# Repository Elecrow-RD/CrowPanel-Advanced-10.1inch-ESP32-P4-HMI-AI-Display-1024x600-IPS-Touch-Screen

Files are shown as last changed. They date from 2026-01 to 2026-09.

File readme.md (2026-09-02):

### 1, Product picture



### 2, Product version number

| | Hardware | Software | Remark |
| ---- | --- | --- | --- |
| 1 | V1.0 | V1.0 | old |
| 1 | V1.1 | V1.1 | old |
| 1 | V1.2 | V1.2 | latest |

**Version 1.1 Update**

The C6 module version 1.1 adds support for 4-wire SDIO communication. Additionally, the arrangement of the SDIO pins has been adjusted, with the pin mappings of the data lines D0–D3 changing from **IO14, IO15, IO16, IO17** to **IO17, IO16, IO15, IO14**. 

**Version 1.2 Update** 

Based on the V1.1 version, V1.2 further optimized the communication stability of the LoRa wireless module. At the same time, the signal pins of the wireless module socket were re-allocated: the original **IO53 and IO54** were adjusted to **IO27 and IO28** respectively, and correspondingly, **IO27 and IO28** were adjusted to **IO53 and IO54** respectively.

### 3, product information

| **Main Chip-ESP32-P4NRW32** | |
| --- | --- |
| CPU/SoC | **ESP32-P4**RISC-V 32-bit dual-core processor for HP systems, running at up to 400 MHz; RISC-V 32-bit single-core processor for LP systems, running at up to 40 MHz |
| System Memory | 768 KB L2MEM（HP）32 KB SRAM（LP）8 KB TCM 32 MB PSRAM |
| Memory | 128 KB ROM（HP）16 KB ROM（LP）16 MB Flash |
| Development Environment | ESP-IDF、Arduino IDE |
| **Screen** | |
| Size | 10.1 inch |
| Resolution | 1024*600 |
| Display Panel | IPS Panel |
| Touch Panel | Capacitive Touch, Single/5-point Touch |
| Viewing Angle | 178° |
| Brightness | 400 cd/m²(Typ.) |
| Color Depth | 16.7M (8-bit) |
| **Wireless Communication - Onboard Antenna** | |
| WiFi | Support 2.4GHz(Wi-Fi6), 802.11a/b/g/n |
| Bluetooth | Support Bluetooth 5.3 and BLE |
| Other | Zigbee、LoRa、nRF2401、Matter、Thread and Wi-Fi Halow (Optional) |
| **Interface/Function** | |
| Interface | USB2.0, UART, I2C, GPIO female headers, SD card holder, battery socket, speaker jack, camera header, module female headers, etc. |
| Function | Audio amplifier, battery charge management, USB to UART, dual microphones, etc. |
| **Button/LED Indicator** | |
| Reset Button | Yes, press to reset device |
| Boot Button | Yes, press and hold the power button to burn the program |
| Power Button | Switch On/Off |
| PWR | Device power on/off indication |
| CHG | Lithium battery charging status, Low battery state |
| **Other** | |
| Installation method | All around mounting holes(M3 3.2mm), embedded, shell assembly |
| Operating temperature | -20~70 °C |
| Storage temperature | -30~80 °C |
| Power Input | 5V/2A, USB or UART terminal |
| Dimensions | 248*147mm |

### Functional description of the product's internal interfaces:

| Pin Name | Description | Connector Type |
| :--- | :--- | :--- |
| SPK | Output audio signals to connect to speakers. The main board comes with a power amplifier chip circuit. | PH2.0-2P |
| PWR | Power LED. | |
| RST | Reset button. Press it to reset the system. | |
| boot | | |
| UART1 | Builds communication between Logic modules, including the serial communication module and the print module. | HY2.0-4P |
| I2C | Builds communication between Logic modules, including the serial communication module and the print module. | HY2.0-4P |
| UART3-IN | Input power supply and serial communication functionality | XH2.54-4P |
| BAT | Connect the lithium battery. (with battery charging circuit) | PH2.0-2P |

### 4, Use the driver module

| Name | dependency library |
| ---- | --- |
| LVGL | lvgl/lvgl@9.1(V1.2)<br />lvgl/lvgl@8.3(V1.0/V1.1) |

### 5,Quick Start
##### ESP-IDF starts

**Note**: This is an IDF course. Before proceeding, ensure you have **Visual Studio Code** and the **IDF **environment installed. The IDF version must be **5.4.2** or higher.

1.Right-click on an empty space in the project folder and select "Open with VS Code" to open the project.


2.In the IDF plug-in, select the port, then compile and flash



### 6,Folder structure.
|--3D file： Contains 3D model files (.stp) for the hardware. These files can be used for visualization, enclosure design, or integration into CAD software.

|--Datasheet: Includes datasheets for components used in the project, providing detailed specifications, electrical characteristics, and pin configurations.

|--Eagle_SCH&PCB: Contains **Eagle CAD** schematic (`.sch`) and PCB layout (`.brd`) files. These are used for circuit design and PCB manufacturing.

|--example: Provides example code and projects to demonstrate how to use the hardware and libraries. These examples help users get started quickly.

|--factory_firmware: Stores pre-compiled factory firmware that can be directly flashed onto the device. This ensures the device runs the default functionality.

|--factory_sourcecode:  Contains the source code for the factory firmware, allowing users to modify and rebuild the firmware as needed.

|--libraries: Includes necessary libraries required for compiling and running the project. These libraries provide drivers and additional functionalities for the hardware.

### 7,Pin definition

#### ESP32-P4 10.1 inch and IPS Display Wiring Pins:
**DSI = Display Serial Interface**is a high-speed, low-power display interface standard defined by the MIPI Alliance, most commonly used in smartphones, tablets, Raspberry Pi devices, and embedded Linux systems.



DSI Pin connection

DSI_DATAN0--IO40

DSI_DATAN0--IO39

DSI_DATAN0--IO36

DSI_DATAN0--IO35

DSI_CLKN--IO37

DSI_CLKP--IO38

DSI_REXT--IO34

#### ESP32-P4 and Touch Driver Wiring：
i2c address: 0x5D/0x14.(The INT pin level during reset of the GT911 touch chip determines the device address.)

INT Low Level(0x5D);

INT High Level(0x14).



Pin connection

I2C1_SCL(IO46)

I2C1_SDA(IO45)

INT_TP(IO42)

RESET_TP(IO40)

#### ESP32-P4 and wireless module wiring pins：

Output voltage: 3.3V Output current: 1A max. Use: The power supply communicates with the wireless module.



Pin connection

#define RADIO_GPIO_CLK 8

#define RADIO_GPIO_MISO 7

#define RADIO_GPIO_MOSI 6

#ifdef CONFIG_BSP_SX1262_ENABLED

#define SX1262_GPIO_BUSY 9

#define SX1262_GPIO_IRQ 53

#define SX1262_GPIO_NRST 54

#define SX1262_GPIO_NSS 10

#ifdef CONFIG_BSP_NRF2401_ENABLED

#define NRF24_GPIO_IRQ 9

#define NRF24_GPIO_CE 53

#define NRF24_GPIO_CS 54

ESP32-P4 and Audio out：



Pin connection

#define AUDIO_GPIO_LRCLK    21   // GPIO pin number for LRCLK (Left-Right Clock)

#define AUDIO_GPIO_BCLK     22   // GPIO pin number for BCLK (Bit Clock)

#define AUDIO_GPIO_SDATA    23   // GPIO pin number for SDATA (Serial Data)

#define AUDIO_GPIO_CTRL     30   // GPIO pin number for audio amplifier control

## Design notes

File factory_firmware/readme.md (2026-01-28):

# How to install the factory demo firmware with flash download tool?

#### 1.Preparation:

- USB C cable
- Laptop/PC
- CrowPanel Advanced 7inch ESP32-P4 HMI AI Display
- Flash download tool

Check whether the materials on the PCBA board are defective. Such as less material, false welding, tin and other bad phenomena.

#### 2.Flash the firmware 

##### Step1 Connect the ESP32 P4 display to the laptop/PC with USB-C cable. The power indicator will light up.

##### Step2 Open the flash download tool. 

flash02

For the  Crowpanel Advance HMI ESP32 P4  AI Display, the chip select ESP32-P4:

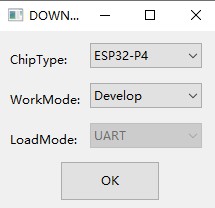
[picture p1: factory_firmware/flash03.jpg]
flash03


##### Step3

①Choose the firmware files;

②Enter the address: 

bootloader.bin------0x2000

partitions-table.bin--------0x8000

esp_brookesia_demo.bin------0x10000

storage.bin-------0xb10000

③Check the firmware files;

④Select the correct port number;

⑤Click “Start” to download

flash1

##### Step4 Press the reset button to show the demo.

#####

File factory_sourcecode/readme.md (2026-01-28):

Factory display code to show the boot screen and the official lvgl display case.
When users re-download the factory cases, they need to first put the libraries in the link in libraries as required.

Factory codes are compiled by IDF.

### Program download link: https://drive.google.com/drive/folders/1gTY6aRsqKJku3hoj4YmE7d5dIDBvLP6W?usp=sharing

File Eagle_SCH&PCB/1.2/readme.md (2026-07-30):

# ESP32-P4 Display 10.1 inch V1.2 Product Hardware Driver Guide

| Item | Details |
|---|---|
| Document Version | V1.0 |
| Applicable Hardware | ESP32-P4 Display 10.1 inch V1.2 |
| Document Date | 2026-07-30 |
| Author | OpenAI Codex (compiled from the project schematics and validation code) |
| Schematic Baseline | `1.2/ESP32-P4 Display 10.1 inch V1.2.sch` and the PDF of the same name |
| Driver Baseline | `idf-code/Lesson01` through `Lesson17` |
| Software Platform | ESP-IDF, primarily targeting ESP32-P4; FreeRTOS |

## 1. Document Purpose and Evaluation Criteria

This document is intended for hardware maintenance, ESP-IDF driver porting, and onboarding handoffs. Cross-validation follows this order of precedence:

1. Constants and initialization code that are actually compiled in the validated BSP;
2. Default Kconfig values and component dependencies in the code;
3. Eagle `.sch` components and netlist;
4. Visual/textual annotations in the PDF schematic;
5. Comments and README files, used only as supplementary information.

When the code and schematic differ, this document records the code values as the “currently effective configuration” while retaining the schematic values in the discrepancy table. The code repository does not include a complete mass-production firmware project, the actual `sdkconfig`, test logs, or module firmware. Therefore, “validated” means that the repository provides a standalone Lesson example for the feature; it does not mean that all peripherals can operate simultaneously.

Status definitions:

- **Code-validated**: The repository contains complete initialization and usage examples.
- **Hardware-confirmed**: The hardware is present in the schematic, but the repository provides no direct driver, or it is managed internally by the chip/module firmware.
- **Optional external device**: Connected through an expansion connector; not an onboard component.
- **NC**: Explicitly marked as not populated in the schematic; must not be treated as a standard installed component.

## 2. System Architecture and Peripheral Overview

| Category | Component/Function | Schematic Designator | Interface | Current Status | Primary Code |
|---|---|---:|---|---|---|
| Main Controller | ESP32-P4NRW32 | U7 | Internal peripheral matrix | Code-validated | All Lessons |
| Boot Storage | W25Q128JVSIQ 128 Mbit NOR Flash | IC11 | Dedicated QSPI | Hardware-confirmed; managed by ROM/IDF | No standalone BSP |
| Wireless Coprocessor | ESP32-C6-MINI-1-N4 | IC1 | 6-line SDIO + EN | Code-validated | Lesson16, 17 |
| Display | 10.1-inch 1024×600, EK79007 timing controller | J21 | 2-lane MIPI-DSI/DPI | Code-validated | Lesson07, 09, 13-16 |
| Touch | GT911 (on the touch FPC/display module) | FPC2 | I2C + RST + INT | Code-validated | Lesson05, 06, 09, 16 |
| Backlight | MT9201 boost constant-current driver | U6 | GPIO31 PWM/EN, GPIO29 power gating | Partially code-validated | `bsp_illuminate` |
| Camera | SC2336 module | FPC1 | 2-lane MIPI-CSI + SCCB | Code-validated | Lesson13 |
| Memory Card | microSD | J5 | SDMMC 1-bit | Code-validated | Lesson08, 12 |
| Audio Output | I2S digital audio + ES8311/NS4168/NS4263B path | IC6/U3/U4 | I2S + I2C + GPIO | Partially code-validated | Lesson11, 12 |
| Audio Input | Onboard PDM microphone; additional ES7210 multichannel ADC | -/IC5 | PDM; I2S+I2C | PDM code-validated; ES7210 hardware-confirmed only | Lesson11 |
| USB Device | USB 2.0 OTG Type-C | J16 | ESP32-P4 USB D+/D- | Code-validated | Lesson06 |
| USB-to-Serial | CH340K + Type-C | U1/J1 | USB-UART0 | Hardware-confirmed; OS driver | Programming/logging port |
| UART Expansion | UART1, UART3/5 V input | J2/J10 | 3.3 V UART, level-shifted 5 V UART | UART1/2 code-validated | Lesson04, 14, 15 |
| I2C Expansion | HY2.0 4P, 7P Header | J13/J11 | 3.3 V I2C | Code-validated | Lesson05, 09, 10 |
| Environmental Sensor | DHT20 (external) | J13 | I2C | Code-validated | Lesson10 |
| LoRa | SX1262 (external) | J9/J11 | SPI + BUSY/IRQ/RST/NSS | Code-validated; Kconfig pin discrepancies | Lesson14 |
| 2.4 GHz | nRF24L01 (external) | J9/J11 | SPI + IRQ/CE/CS | Code-validated; Kconfig pin discrepancies | Lesson15 |
| GPIO Expansion | 2×12 Header | J7 | GPIO2-5, 25, 49-54, 3.3/5 V | Hardware-confirmed | User application |
| Buttons | P4 RESET, BOOT | K4/K3 | CHIP_PU, boot configuration | Hardware-confirmed | ROM boot logic |
| Battery Charging | TP4059 + battery connector | U2/J3 | Analog power, CHG/STD | Hardware-confirmed | Monitored by STC8 auxiliary controller |
| Power Auxiliary Controller | STC8H1K08-36I | U5 | ADC/GPIO/SPI/UART | Hardware-confirmed; no source code | None |
| Power Tree | RY3420, MT3406, MT3608, ME6211 series | U9/U10/U16/IC2/3/4/7/8 | DC-DC/LDO | Hardware-confirmed | ESP32-P4 internal LDOs are invoked |

## 3. Currently Effective ESP32-P4 Pin Assignment Table

| GPIO/Dedicated Pin | Current Function | Electrical/Multiplexing Notes | Code Basis |
|---:|---|---|---|
| 6/7/8 | External wireless SPI MOSI/MISO/SCLK | SPI3_HOST, 8 MHz; J9 through series resistors/filtering | Lesson14/15 `bsp_wireless.h` |
| 9/10 | SX1262 BUSY/NSS or nRF24 IRQ | Mutually exclusive between modules | Lesson14/15 |
| 12/13 | Camera SCCB SDA/SCL | I2C1, internal pull-ups, 100 kHz | Lesson13 |
| 14/15/16/17/18/19 | ESP32-C6 SDIO D3/D2/D1/D0/CLK/CMD | Dedicated onboard 6-line bus | Lesson16/17 + schematic |
| 20 | Microphone L/R selection | Schematic net `MIC_L/R`; not configured by the current PDM BSP | Schematic |
| 21/22/23 | I2S LRCLK/BCLK/DOUT | 16 kHz, 16 bit, stereo | Lesson11/12 |
| 24/26 | PDM CLK/DIN | 16 kHz mono, left channel | Lesson11 |
| 25 | GPIO expansion | J7-17 | Schematic |
| 27/28 | UART2 TX/RX; J9/J11 wireless control pins, used by the BSP as IRQ/RST or CE/CS | **The schematic intentionally multiplexes these signals; software must ensure mutual exclusion** | Schematic + Lesson14/15 |
| 29 | LCD backlight power MOS gate | Present in the schematic; not controlled by the current display BSP | Schematic |
| 30 | Audio amplifier control | Push-pull output; active-low in code | Lesson11/12 |
| 31 | LCD backlight PWM/EN | LEDC 30 kHz, 11 bit | Lesson07+ |
| 32 | ESP32-C6 EN | Main controller can reset/power down the C6; examples do not operate it directly | Schematic |
| 33/34 | UART3 RX/TX (5 V input expansion) | Level-shifted to J10 | Defined in Lesson04 but this pin group is not selected |
| 37/38 | UART0 TX/RX | CH340K programming/logging | Schematic |
| 39/43/44 | microSD D0/CLK/CMD | SDMMC slot 0, 1-bit, 10 MHz | Lesson08/12 |
| 40/42 | GT911 RST/INT | Configured active-low; current driver primarily uses polling | Lesson05/09 |
| 41 | LCD RESET | Connected in the schematic; EK79007 BSP uses `reset_gpio_num=-1` | Discrepancy; see Section 15 |
| 45/46 | System I2C SDA/SCL | I2C0, open-drain, internal pull-ups, 400 kHz | Lesson05/09/10/16 |
| 47/48 | UART1 TX/RX | J2 3.3 V; GPIO48 is also used by the LED example | Lesson02/04 + schematic |
| 49-54 | GPIO expansion | J7; 53/54 are the wireless Kconfig-recommended control pins | Schematic/Kconfig |
| USB DP/DM | USB2 D+/D- | Dedicated PHY to J16 | Lesson06 |
| Dedicated DSI/CSI Pins | MIPI D-PHY | Two data lanes plus one clock lane each | Lesson07/13 |

## 4. Main Controller, Clocks, and Boot Storage

### 4.1 ESP32-P4NRW32 (U7)

- All main-controller examples are based on ESP-IDF/FreeRTOS; the code uses the IDF driver layer rather than directly accessing chip registers.
- The external main crystal Y2 is 40 MHz; Y4 is 32.768 kHz.
- K4 pulls `CHIP_PU/P4_RST_EN` low to reset the device; K3 controls `SPI_BOOT`. The schematic labels high as SPI Boot and low as Download Boot.
- High-bandwidth display/camera buffers depend on SPIRAM. LVGL uses double buffering in SPIRAM, while the camera uses cache-aligned SPIRAM USERPTR buffers.
- The display/wireless examples acquire the ESP32-P4 internal LDO3 at 2500 mV and LDO4 at 3300 mV before initializing peripherals. This sequence must not be omitted during porting.

```c
esp_ldo_channel_config_t ldo3 = { .chan_id = 3, .voltage_mv = 2500 };
esp_ldo_channel_config_t ldo4 = { .chan_id = 4, .voltage_mv = 3300 };
ESP_ERROR_CHECK(esp_ldo_acquire_channel(&ldo3, &ldo3_handle));
ESP_ERROR_CHECK(esp_ldo_acquire_channel(&ldo4, &ldo4_handle));
```

### 4.2 W25Q128JVSIQ (IC11)

- Dedicated Flash bus: `FLASH_CS/CK/WP/HOLD/D/Q`; it does not use peripheral pins listed in the general-purpose GPIO table.
- The component model indicates a capacity of 128 Mbit (16 MiB). Actual usable partitions are determined by the project’s `partitions.csv` and flashing configuration.
- It is managed by the ROM bootloader and the ESP-IDF SPI flash layer. The application must not initialize this bus again.

## 5. Display, Touch, and Backlight

### 5.1 EK79007 MIPI-DSI Display

Currently effective parameters: 2 data lanes, 900 Mbps lane rate, 8-bit DBI commands and parameters; 1024×600, RGB565, 51 MHz DPI pixel clock; horizontal timing 160/70/160 and vertical timing 23/10/12 (back porch/pulse/front porch).

```c
esp_lcd_dsi_bus_config_t bus = {
    .bus_id = 0, .num_data_lanes = 2, .lane_bit_rate_mbps = 900,
};
esp_lcd_dpi_panel_config_t dpi = {
    .dpi_clock_freq_mhz = 51,
    .pixel_format = LCD_COLOR_PIXEL_FORMAT_RGB565,
    .video_timing = { .h_size=1024, .v_size=600,
        .hsync_back_porch=160, .hsync_pulse_width=70, .hsync_front_porch=160,
        .vsync_back_porch=23, .vsync_pulse_width=10, .vsync_front_porch=12 },
};
```

Dependencies: `esp_lcd_mipi_dsi`, `espressif/esp_lcd_ek79007 ^1.0.2`, `esp_lvgl_port ^2.6.0`, and LVGL 8.3.11. The LVGL task priority is `configMAX_PRIORITIES-4`, with a 16 KiB stack, a 5 ms timer, and a maximum sleep duration of 10 ms; full-frame double buffers reside in SPIRAM.

### 5.2 GT911 Touch

- I2C0: SDA=GPIO45, SCL=GPIO46; 7-bit address, 400 kHz; internal pull-ups enabled and a 7-cycle glitch filter.
- RST=GPIO40 and INT=GPIO42, both configured with active level 0; coordinates are 1024×600, with no XY swap or mirroring.
- The driver first attempts `ESP_LCD_TOUCH_IO_I2C_GT911_ADDRESS`, then tries `..._BACKUP` if the first attempt fails (common GT911 addresses are 0x5D/0x14; the final values are determined by the component header).
- The application polling path calls `esp_lcd_touch_read_data()`. Although INT is passed to the component, the examples do not register a user GPIO ISR.

Initialization sequence: acquire LDOs → `i2c_init()` → `touch_init()` → DSI/LVGL → register the LVGL touch input → turn on the backlight.

### 5.3 Backlight

- GPIO31 connects to MT9201 EN/backlight control, using LEDC low-speed timer0/channel0, the PLL divider clock, 30 kHz, and 11-bit resolution.
- `brightness=0` outputs duty 0; for nonzero values, duty=`brightness*18+200`. The caller must limit the value to 0-100, or the duty may exceed the 11-bit maximum of 2047.
- The schematic also includes GPIO29→Q11→`LCD_BK_VDD` power gating. The current BSP does not drive GPIO29 high; whether it is controlled by the power-on default or other firmware must be confirmed on physical hardware.
- The J21 panel also requires analog supplies such as 9.6 V AVDD, 18 V VGH, -6 V VGL, and 3.3 V VCOM. These are generated by U16/discrete circuitry and are not GPIO-driven.

## 6. SC2336 Camera

- FPC1 connector: 2-lane MIPI-CSI (D0/D1/CLK differential pairs), SCCB, XVCLK, RESET, and DOVDD 1.8 V/AVDD 2.8 V power supplies.
- SCCB uses I2C port 1, SDA=GPIO12 and SCL=GPIO13, with internal pull-ups at 100 kHz.
- The driver configures `reset_pin=-1` and `pwdn_pin=-1`, reuses the existing SCCB bus handle, and uses `ESP_VIDEO_MIPI_CSI_DEVICE_NAME` as the video node.
- RGB565 is enforced through V4L2 `VIDIOC_G_FMT/S_FMT`; the resolution is negotiated by the sensor driver and is not hard-coded in the BSP.
- At least two capture buffers are used with `V4L2_MEMORY_USERPTR`, SPIRAM, and cache alignment; H/V flip can be controlled through Kconfig.
- ISP parameter file `sc2336_custom.json`: 50 Hz anti-flicker, including AWB/AGC, noise reduction, gamma, sharpening, and a color matrix.
- Dependencies: ESP-IDF >=5.4.0, `esp_cam_sensor ^1.2.0`, `esp_sccb_intf ^0.0.5`, and `esp_video ^1.1.0`.

Note: The schematic includes a `CSI_RESET` control net, but the code explicitly uses -1. Retain the code configuration during migration unless the GPIO reset path is revalidated.

## 7. microSD

- GPIO43=CLK, GPIO44=CMD, and GPIO39=D0; SDMMC_HOST slot 0, 1-bit, 10 MHz, with internal pull-ups.
- J5 D1, D2, and CS are not used in the current 1-bit mode; the corresponding pads/pull-ups are also visible in the schematic.
- The FATFS mount point is `/sdcard`; automatic formatting is disabled, up to five files may be open, and the allocation unit is 16 KiB.

```c
sdmmc_host_t host = SDMMC_HOST_DEFAULT();
host.slot = SDMMC_HOST_SLOT_0;
host.max_freq_khz = 10000;
sdmmc_slot_config_t slot = SDMMC_SLOT_CONFIG_DEFAULT();
slot.clk = GPIO_NUM_43; slot.cmd = GPIO_NUM_44; slot.d0 = GPIO_NUM_39;
slot.width = 1; slot.flags |= SDMMC_SLOT_FLAG_INTERNAL_PULLUP;
```

The current BSP does not use card-detect CD for hot-plug detection. FATFS should be unmounted before inserting or removing the card to avoid file-system corruption.

## 8. Audio Input and Output

### 8.1 Currently Validated Playback Path

- GPIO21=LRCLK/WS, GPIO22=BCLK, and GPIO23=DOUT; I2S standard TX, 16 kHz, 16 bit, stereo, with an MCLK multiple of 256, but `mclk=I2S_GPIO_UNUSED`.
- GPIO30 controls the audio amplifier and is configured as a push-pull output with no pull-up or pull-down. In the code, `set_Audio_ctrl(true)` actually outputs a low level, so the control is active-low.
- The Lesson12 SD audio playback example uses the same GPIOs; the input file format/sample rate must match the actual I2S configuration.

### 8.2 Currently Validated Recording Path

- PDM RX: GPIO24=CLK and GPIO26=DIN; 16 kHz, 16 bit, mono, left slot.
- 8× downsampling, BCLK divider 8, 35.5 Hz high-pass, and amplify=1.
- The recording buffer is allocated at 32000 bytes/s. The example limits recordings to 60 seconds and, after recording, converts and plays them back through the playback path.

### 8.3 Audio Components Present in the Schematic but Not Fully Driven by the Examples

- ES7210 (IC5): multichannel audio ADC with I2C control and I2S/TDM output; the repository does not contain register initialization.
- ES8311 (IC6): codec with I2C control lines on the 3.3 V side, connected to I2S MCLK/SCLK/LRCK/SDOUT; the current playback BSP does not initialize its I2C registers.
- NS4168 (U3/U13) is marked NC in the schematic and must not be treated as a standard installed amplifier.
- NS4263B (U4) is the onboard analog amplifier path; the enable/disable and mute polarity should still be confirmed using waveforms from physical hardware.

## 9. USB and Serial Ports

### 9.1 USB2 Device Port J16

- Dedicated USB DP/DM connects directly to the ESP32-P4; both Type-C CC pins have 5.1 kΩ pull-down resistors, configuring the port as a device.
- Lesson06 uses a TinyUSB HID mouse: one HID interface, IN endpoint 0x81, 16-byte packets, and a 10 ms interval; it declares 100 mA and remote wakeup.
- Dependency: `espressif/esp_tinyusb ^1.1`. Touch is polled every 10 ms and converted into relative mouse movement.

### 9.2 USB-UART Programming Port J1/U1

- The CH340K connects to USB1 D+/D-, with UART0 connected to ESP32-P4 GPIO37 (TX)/GPIO38 (RX); DTR/RTS participate in automatic programming/reset.
- The application does not initialize the CH340K; the host PC uses the WCH CH340 driver. This port is used for both programming and logging, so the application should not remap UART0.

### 9.3 UART Expansion

- J2: 3.3 V UART1, GPIO47 TX and GPIO48 RX.
- J10: external 5 V UART input interface, connected through level shifting to GPIO34 TX and GPIO33 RX.
- Lesson04 actually initializes `UART_NUM_2` and maps it to GPIO47/48: 115200, 8N1, no flow control, and a 2048-byte RX buffer.
- Lesson14/15 optionally use `UART_NUM_1` at 115200 8N1 for transparent UART communication. GPIO27/28 in the header match the J9/J11 schematic connections, but the Kconfig defaults specify GPIO53/54 instead.

## 10. Onboard ESP32-C6 Wi-Fi

- The ESP32-P4 itself has no Wi-Fi; IC1 ESP32-C6-MINI-1-N4 serves as the wireless coprocessor.
- SDIO: P4 GPIO14/15/16/17/18/19 → C6 IO23/22/21/20/19/18 (D3/D2/D1/D0/CLK/CMD). GPIO32 controls C6 EN.
- The C6 has its own UART0 and BOOT test/programming network; do not confuse it with the P4 application UART.
- P4 software depends on `espressif/esp_hosted ~2.7.0` and `espressif/esp_wifi_remote ^0.16.1`; the application still calls the standard `esp_wifi_*` API.
- Lesson17 covers STA, SoftAP, and AP+STA; the channel, maximum number of connections, and authentication threshold are controlled by Kconfig. The Lesson16 weather application uses STA.

Porting must ensure all of the following: the C6 is flashed with slave firmware compatible with the esp-hosted version; the P4 SDIO pin/width configuration matches the board-level connections; and the GPIO32 EN timing is correct. The repository does not include the C6 slave firmware or the complete system `sdkconfig`; these are external dependencies for reproducing Wi-Fi operation.

## 11. I2C Environmental Sensor and Expansion Ports

System I2C0 (GPIO45/46) connects to J13/J11 and the onboard codec control interface through BSS138 level shifting/pull-ups. The code uniformly configures bus devices for 7-bit addressing at 400 kHz.The DHT20 is an external device at address 0x38:

- After initialization, check the calibration status bits: `status & 0x18 == 0x18`;
- Send the measurement command `AC 33 00`, wait at least 80 ms, and then poll the busy bit;
- Read 7 bytes. CRC-8 uses an initial value of 0xFF and polynomial 0x31;
- Humidity and temperature are both 20-bit values and must be converted to `%RH` and `°C`.

The touchscreen, DHT20, ES8311, and external devices share bandwidth on the same I2C0 bus. Address conflicts and the total pull-up resistance must be checked before connecting a new module.

## 12. External Wireless Modules

### 12.1 Shared SPI Bus

SPI3_HOST, GPIO8 SCLK, GPIO7 MISO, GPIO6 MOSI, mode 0, 8 MHz, DMA auto; CS is controlled in software by RadioLib through a GPIO, with `spics_io_num=-1`. J9 provides SPI and 3.3/5 V, while the control pins come from additional expansion GPIOs.

### 12.2 SX1262 (Lesson14)

Current valid header-file values: BUSY=GPIO9, IRQ/DIO1=GPIO27, NRST=GPIO28, and NSS=GPIO10; these values match the J9/J11 connections. LoRa parameters: 915 MHz, BW 125 kHz, SF7, CR 7, private sync word, 22 dBm, preamble 8, and TCXO voltage parameter 1.6. TX/RX completion uses GPIO ISR callbacks. RX uses continuous receive with boosted gain.

### 12.3 nRF24L01 (Lesson15)

Current valid header-file values: IRQ=GPIO9, CE=GPIO27, and CS=GPIO28; these values match the J9/J11 connections. Parameters: 2400 MHz, 250 kbps, address width 5, pipe address `01 02 11 12 FF`, and SPI at 8 MHz.

The SX1262 and nRF24 share the SPI bus and control pins, so only one may be selected at compile time. Product compliance must confirm whether 915 MHz complies with regulations in the deployment region.

## 13. Power, Charging, and Auxiliary Control

| Power Domain/Device | Function | Software Relationship |
|---|---|---|
| TP4059 U2 | Single-cell lithium battery charging from 5 V input, CHG/STD status | Monitored by STC8; no direct P4 control |
| STC8H1K08 U5 | Charging LEDs, VBAT ADC, power control | No STC8 firmware in the repository; maintenance gap |
| U9 RY3420 | 5 V→3.3 V DC-DC | Always on/hardware-enabled |
| U10 MT3406 | 5 V→approximately 1.2 V DC-DC | P4 DCDC power domain |
| U16 MT3608 | Front-end power supply for LCD high voltage | Hardware-controlled |
| IC2 ME6211 1.8 V | Camera DOVDD | Hardware-enabled |
| IC3 ME6211 2.8 V | Camera AVDD | Hardware-enabled |
| IC4 ME6211 1.8 V NC | Alternative LCD VDD | NC, not required |
| IC7/IC8 ME6211 3.3 V | Audio/auxiliary control power | Hardware-enabled |
| MT9201 U6 | Constant-current boost converter for LCD LEDs | GPIO31 EN/PWM |
| GPIO29/Q11 | Backlight input power gating | Currently omitted from the BSP; must be verified on actual hardware |

Type-C J1, J16, and the external 5 V input provide multiple power entry points, and the schematic includes diode/MOSFET isolation. During maintenance, never bypass the isolation and connect different power supplies in parallel. All expansion GPIOs use 3.3 V logic. Only J10, which is explicitly marked as having level conversion, can accept 5 V UART signals.

## 14. Expansion Connectors

| Connector | Key Signals | Voltage/Purpose |
|---|---|---|
| J7 2×12 | GPIO49, 2, 3, 4, 5, 50, 51, 52, 25, 53, 54 | Includes 3.3 V, 5 V, and GND; GPIOs are not 5 V tolerant |
| J9 7P | SPI SCLK/MISO/MOSI, GPIO27, 3.3 V, 5 V, GND | External SX1262/nRF24 |
| J11 7P | I2C SDA/SCL, GPIO28/9/10 | Wireless/I2C expansion |
| J13 HY2.0 | 3.3 V, SDA, SCL, GND | DHT20 and other I2C sensors |
| J2 HY2.0 | RXD1, TXD1, 3.3 V, GND | 3.3 V UART |
| J10 XH2.54 | UART_IN TX/RX, 5 V, GND | External UART with level conversion |
| J8 1×4 | STC8 power/programming-related signals | For auxiliary-control maintenance only |

## 15. Schematic and Code Differences/Conflicts

| ID | Item | Schematic/Kconfig | Current Working Code | Assessment and Handling |
|---|---|---|---|---|
| D01 | Wireless control pin configuration | Both schematic J9/J11 and the header file use GPIO27/28; Kconfig defaults to GPIO53/54 | GPIO27/28 hardcoded in the header file | Record 27/28 based on the effective code and schematic; the Kconfig values are currently ineffective. If changed to 53/54, the external wiring must also be changed and revalidated |
| D02 | Wireless configuration source | Kconfig defines `CONFIG_*GPIO*` | The header file does not reference Kconfig and instead defines macros directly | Changes in menuconfig do not take effect; migration requires standardizing on `CONFIG_...` |
| D03 | GPIO48 LED | The schematic shows GPIO48 as `RXD1` routed to J2; no independent onboard LED net was found | Lesson02 directly configures GPIO48 as push-pull output and describes high level as “LED on” | Record as operational according to the example, but it drives the UART RX net; do not use it simultaneously with UART1. Verify the silkscreen/board revision on actual hardware |
| D04 | LCD reset | J21 `LCD_RESET` connects to P4 GPIO41 | EK79007 uses `reset_gpio_num=-1` | Do not use GPIO reset according to the code; verify GPIO41 timing only if cold-start issues occur |
| D05 | Backlight power | GPIO29 controls Q11 `LCD_BK_VDD` | The BSP controls only GPIO31 PWM | May depend on a default pull-up or other firmware; GPIO29 must be tested and incorporated into production initialization |
| D06 | Camera reset | FPC1 has a `CSI_RESET` hardware net | `reset_pin=-1`, `pwdn_pin=-1` | Follow the code; do not independently drive shared pins such as GPIO46 based solely on the schematic |
| D07 | SD data width | J5 routes D0/D1/D2/CS | D0 only, 1-bit SDMMC | Not a conflict; follow the code for a more reliable 10 MHz 1-bit mode |
| D08 | Audio codec | The schematic includes ES7210/ES8311 | The examples use I2S/PDM directly without writing codec registers | Only demonstrates a simplified audio path; full codec functionality requires new driver validation |
| D09 | UART naming | Schematic signal names are UART1/UART3/UART2 | Lesson04 maps `UART_NUM_2` to GPIO47/48 | IDF UART controllers can be routed through the GPIO matrix; use GPIOs rather than variable names when determining connections during maintenance |
| D10 | GT911 address | The schematic does not specify the chip address | The component automatically tries the primary and alternate addresses | Follow the code; record the final address in the logs for maintenance |
| D11 | NS4168 | U3/U13 are marked NC | Audio descriptions may refer generically to an amplifier | Follow the BOM/actual hardware; do not create hard dependencies on NC devices |

The causes of these differences can be conclusively determined only after obtaining the hardware ECN, BOM, and test records. Current possibilities include unsynchronized board revisions, remnants from example migrations, or schematic labeling errors; this document does not treat possible causes as established facts.

## 16. Risks and Precautions

1. **GPIO27/28 resource conflict (High)**: The schematic multiplexes UART2 with the J9/J11 wireless control pins; they cannot be enabled simultaneously. If J7 GPIO53/54 are used instead, both the external wiring and BSP must be updated.
2. **GPIO48 conflict (High)**: The LED example shares a pin with UART1 RX; output mode may cause electrical contention with an external transmitter.
3. **5 V tolerance (High)**: ESP32-P4 GPIOs use 3.3 V logic. The presence of 5 V on J7/J9 does not mean the signal pins are 5 V tolerant.
4. **Backlight power sequencing (High)**: Complete DSI initialization and render the first frame before enabling GPIO29 power and GPIO31 PWM; use the reverse order during shutdown.
5. **Wi-Fi firmware coupling (High)**: The P4 `esp_hosted/esp_wifi_remote` version must match the C6 slave firmware.
6. **Power entry points (High)**: When USB, battery, and external 5 V supplies coexist, confirm that the isolation components are installed; never short the supplies together directly.
7. **MIPI signal integrity (High)**: DSI/CSI are controlled-impedance differential signals. Do not use jumper wires, long leads on ordinary probes, or arbitrary FPC substitutions.
8. **Memory pressure (Medium)**: A single 1024×600 RGB565 frame is approximately 1.17 MiB. Display double buffering plus camera double buffering requires sufficient SPIRAM.
9. **I2C pull-ups (Medium)**: Multiple onboard and external pull-ups connected in parallel may be too strong. At 400 kHz, verify the waveform and low-level sink current.
10. **SD hot-plugging (Medium)**: Card-detect handling is not currently implemented. Removing the card during writes may corrupt FATFS.
11. **Audio popping (Medium)**: GPIO30 is active low. Keep the amplifier disabled until the data is stable, and disable it only after the stream has stopped.
12. **LoRa regulations (Medium)**: 915 MHz and 22 dBm are not permitted in all regions. Production parameters must be adjusted for the target market.
13. **Security configuration (Medium)**: The Lessons contain example Wi-Fi SSIDs/passwords; they must not be included in production firmware.
14. **Missing auxiliary-control source code (Medium)**: The STC8 firmware is not in the repository, so the charging/power state machine cannot be fully audited or migrated.

## 17. Recommended System Initialization/Shutdown Sequence

Power-on initialization:

1. Confirm that the external 5 V/battery supply is stable, and keep the backlight and amplifier disabled;
2. Configure ESP32-P4 LDO3=2.5 V and LDO4=3.3 V;
3. Initialize the shared I2C0 bus, followed by the GT911 and other I2C devices;
4. Initialize MIPI-DSI, EK79007, and LVGL, and submit the first frame;
5. Confirm the GPIO29 backlight power-gating state, and then gradually increase GPIO31 from a low duty cycle;
6. Initialize the SD card, audio, and camera as needed; initialize camera SCCB before CSI/V4L2;
7. Start the ESP32-C6 and wait for hosted transport, then start `esp_wifi`;
8. Finally, enable the external wireless IRQ or UART after completing GPIO conflict checks.

Reverse the sequence for shutdown: stop application tasks/IRQs → stop Wi-Fi/wireless → stop the camera/release frame buffers → unmount the SD card → stop I2S and disable the amplifier → set backlight duty=0/disable power → release the display and LDOs.

## 18. Driver Migration Checklist

- [ ] Lock the hardware version to V1.2, along with the BOM and ECN; confirm all NC/DNP components.
- [ ] Ensure the target ESP-IDF meets the requirements of all components; standardizing on >=5.4.2 is recommended.
- [ ] Before copying the pin table, define the mutual-exclusion strategy for D01 and resolve D03 and D05.
- [ ] Enable PSRAM and verify DMA/cache alignment capabilities.
- [ ] First run individual tests for solid-color display output, touchscreen coordinates, SD read/write, audio loopback, and camera frame capture.
- [ ] Use a logic analyzer to verify I2C at 400/100 kHz, SPI at 8 MHz, SD at 10 MHz, and UART at 115200.
- [ ] Use an oscilloscope to verify GPIO30/31/29 polarity and power-on waveforms.
- [ ] Flash the matching version of the ESP32-C6 hosted firmware and test reconnection after disconnection.
- [ ] Then perform full-system concurrent stress testing: display + touchscreen + SD + audio + camera + Wi-Fi.
- [ ] Record the final `sdkconfig`, component lock file, C6 firmware hash, and test report.

## 19. Key Software Dependencies and Evidence Index

| Function | Software Layer/Component | Primary Evidence Files |
|---|---|---|
| GPIO/LEDC | ESP-IDF `driver/gpio.h`, `driver/ledc.h` | `Lesson02/.../bsp_extra.c`, `Lesson07/.../bsp_illuminate.c` |
| DSI/LVGL | ESP-IDF LCD + EK79007 + LVGL port | `Lesson07-Turn_on_the_screen/peripheral/bsp_illuminate/` |
| GT911/I2C | New IDF I2C master + esp_lcd_touch_gt911 | `Lesson05-Touchscreen/peripheral/` |
| SD | SDMMC + VFS FAT | `Lesson08-SD_Card_File_Reading/peripheral/bsp_sd/` |
| I2S/PDM | IDF I2S standard/PDM drivers | `Lesson11-Playback_After_Recording/peripheral/` |
| USB | TinyUSB/esp_tinyusb | `Lesson06-USB2.0/peripheral/bsp_usb/` |
| Camera | esp_video/V4L2 + esp_cam_sensor | `Lesson13-Camera_Real-Time/peripheral/bsp_camera/` |
| Wi-Fi | esp_hosted + esp_wifi_remote | `Lesson16.../idf_component.yml`, `Lesson17-Wi-Fi_function/` |
| SX1262/nRF24 | RadioLib 7.x + custom EspHal | `Lesson14.../bsp_wireless/`, `Lesson15.../bsp_wireless/` |
| Schematic Nets | Eagle 9.6.2 XML + PDF | `1.2/ESP32-P4 Display 10.1 inch V1.2.sch/.pdf` |

## 20. Maintenance Conclusions

The board’s verified primary path is ESP32-P4 + MIPI-DSI 1024×600 + GT911 + SDMMC + PDM/I2S + MIPI-CSI + ESP32-C6 hosted Wi-Fi. The schematic and code are generally consistent for the display, touchscreen, SD, camera data interface, primary audio GPIOs, and wireless J9/J11 connections. The main maintenance risks are GPIO27/28 function multiplexing and the Kconfig mismatch, GPIO48 LED/UART multiplexing, omission of backlight GPIO29 from the BSP, and missing source code for full codec/power auxiliary control. Before conducting concurrent multi-peripheral validation, any complete system integration must first resolve these discrepancies.

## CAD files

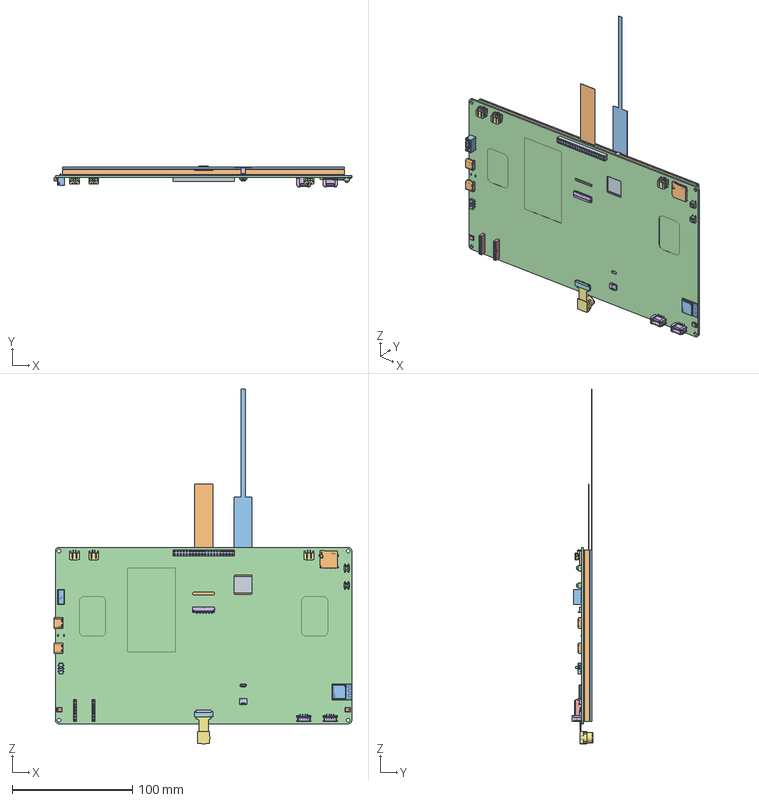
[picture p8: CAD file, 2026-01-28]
3D file/ESP32-P4-10_1-inch-20251230.stp
248.0 x 17.5 x 295.7 mm
LCD-10-1CUN
TP-10-1CUN
PCBA-10-1
FPC1_FPC-SMD_P0_50-24P_QCHF-SM
H1_HDR-SMD_40P-P2_54-V-F-R2-C20
USB-C-SMD_TYPE-C-6PIN-2MD x 2
CN2_CONN-TH_4P-P2_50_4PIN_CONN
LED x 2
HDR-SMD_7P-P2_54_HX-PM2_54-1X7P x 2
U4_CONN-SMD_4P-P2_00 x 2
CONN-SMD_2P-P2_00_BX-PH2_0-2PWT x 3
SW-SMD_MST22D18G2_SW-SMD_MST22D
FPC-SMD_P0_50-6P_QCHF-SM-H2_0_1
TF-SMD
WIFIM-SMD_61P-L16_6-W13_2-P0_80
SW-SMD_4P-L4_5-W4_5-P3_00 x 2
MIC-SMD_6P-L4_7-W3_8-P1_65-TL_M x 2
CONN-SMD_AFC24-S30FIC-00_CONN-S
AS-AG638A32M1-25

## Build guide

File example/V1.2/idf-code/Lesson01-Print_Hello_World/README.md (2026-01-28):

| Supported Targets | ESP32 | ESP32-C2 | ESP32-C3 | ESP32-C5 | ESP32-C6 | ESP32-C61 | ESP32-H2 | ESP32-P4 | ESP32-S2 | ESP32-S3 | Linux |
| --- | ----- | --- | --- | --- | --- | --- | --- | --- | --- | --- | ----- |

# Hello World Example

Starts a FreeRTOS task to print "Hello World".

(See the README.md file in the upper level 'examples' directory for more information about examples.)

## How to use example

Follow detailed instructions provided specifically for this example.

Select the instructions depending on Espressif chip installed on your development board:

- [ESP32 Getting Started Guide](https://docs.espressif.com/projects/esp-idf/en/stable/get-started/index.html)
- [ESP32-S2 Getting Started Guide](https://docs.espressif.com/projects/esp-idf/en/latest/esp32s2/get-started/index.html)

## Example folder contents

The project **hello_world** contains one source file in C language [hello_world_main.c](main/hello_world_main.c). The file is located in folder [main](main).

ESP-IDF projects are built using CMake. The project build configuration is contained in `CMakeLists.txt` files that provide set of directives and instructions describing the project's source files and targets (executable, library, or both).

Below is short explanation of remaining files in the project folder.

```
├── CMakeLists.txt
├── pytest_hello_world.py      Python script used for automated testing
├── main
│   ├── CMakeLists.txt
│   └── hello_world_main.c
└── README.md                  This is the file you are currently reading
```

For more information on structure and contents of ESP-IDF projects, please refer to Section [Build System](https://docs.espressif.com/projects/esp-idf/en/latest/esp32/api-guides/build-system.html) of the ESP-IDF Programming Guide.

## Troubleshooting

* Program upload failure

    * Hardware connection is not correct: run `idf.py -p PORT monitor`, and reboot your board to see if there are any output logs.
    * The baud rate for downloading is too high: lower your baud rate in the `menuconfig` menu, and try again.

## Technical support and feedback

Please use the following feedback channels:

* For technical queries, go to the [esp32.com](https://esp32.com/) forum
* For a feature request or bug report, create a [GitHub issue](https://github.com/espressif/esp-idf/issues)

We will get back to you as soon as possible.

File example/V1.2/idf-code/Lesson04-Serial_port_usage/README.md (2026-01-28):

| Supported Targets | ESP32 | ESP32-C2 | ESP32-C3 | ESP32-C6 | ESP32-H2 | ESP32-P4 | ESP32-S2 | ESP32-S3 |
| --- | ----- | --- | --- | --- | --- | --- | --- | --- |

# Example: GPIO

(See the README.md file in the upper level 'examples' directory for more information about examples.)

This test code shows how to configure GPIO and how to use it with interruption.

## GPIO functions:

| GPIO | Direction | Configuration |
| --- | --- | --- |
| CONFIG_GPIO_OUTPUT_0 | output | |
| CONFIG_GPIO_OUTPUT_1 | output | |
| CONFIG_GPIO_INPUT_0 | input | pulled up, interrupt from rising edge and falling edge |
| CONFIG_GPIO_INPUT_1 | input | pulled up, interrupt from rising edge |

## Test:
 1. Connect CONFIG_GPIO_OUTPUT_0 with CONFIG_GPIO_INPUT_0
 2. Connect CONFIG_GPIO_OUTPUT_1 with CONFIG_GPIO_INPUT_1
 3. Generate pulses on CONFIG_GPIO_OUTPUT_0/1, that triggers interrupt on CONFIG_GPIO_INPUT_0/1

 **Note:** The following pin assignments are used by default, you can change them by `idf.py menuconfig` > `Example Configuration`.

| | CONFIG_GPIO_OUTPUT_0 | CONFIG_GPIO_OUTPUT_1 | CONFIG_GPIO_INPUT_0 | CONFIG_GPIO_INPUT_1 |
| --- | --- | --- | --- | --- |
| ESP32C2/ESP32H2 | 8 | 9 | 4 | 5 |
| All other chips | 18 | 19 | 4 | 5 |

## How to use example

Before project configuration and build, be sure to set the correct chip target using `idf.py set-target <chip_name>`.

### Hardware Required

* A development board with any Espressif SoC (e.g., ESP32-DevKitC, ESP-WROVER-KIT, etc.)
* A USB cable for Power supply and programming
* Some jumper wires to connect GPIOs.

### Configure the project

### Build and Flash

Build the project and flash it to the board, then run the monitor tool to view the serial output:

Run `idf.py -p PORT flash monitor` to build, flash and monitor the project.

(To exit the serial monitor, type ``Ctrl-]``.)

See the [Getting Started Guide](https://docs.espressif.com/projects/esp-idf/en/latest/get-started/index.html) for full steps to configure and use ESP-IDF to build projects.

## Example Output

As you run the example, you will see the following log:

```
I (317) gpio: GPIO[18]| InputEn: 0| OutputEn: 1| OpenDrain: 0| Pullup: 0| Pulldown: 0| Intr:0
I (327) gpio: GPIO[19]| InputEn: 0| OutputEn: 1| OpenDrain: 0| Pullup: 0| Pulldown: 0| Intr:0
I (337) gpio: GPIO[4]| InputEn: 1| OutputEn: 0| OpenDrain: 0| Pullup: 1| Pulldown: 0| Intr:1
I (347) gpio: GPIO[5]| InputEn: 1| OutputEn: 0| OpenDrain: 0| Pullup: 1| Pulldown: 0| Intr:1
Minimum free heap size: 289892 bytes
cnt: 0
cnt: 1
GPIO[4] intr, val: 1
GPIO[5] intr, val: 1
cnt: 2
GPIO[4] intr, val: 0
cnt: 3
GPIO[4] intr, val: 1
GPIO[5] intr, val: 1
cnt: 4
GPIO[4] intr, val: 0
cnt: 5
GPIO[4] intr, val: 1
GPIO[5] intr, val: 1
cnt: 6
GPIO[4] intr, val: 0
cnt: 7
GPIO[4] intr, val: 1
GPIO[5] intr, val: 1
cnt: 8
GPIO[4] intr, val: 0
cnt: 9
GPIO[4] intr, val: 1
GPIO[5] intr, val: 1
cnt: 10
...
```

## Troubleshooting

For any technical queries, please open an [issue](https://github.com/espressif/esp-idf/issues) on GitHub. We will get back to you soon.

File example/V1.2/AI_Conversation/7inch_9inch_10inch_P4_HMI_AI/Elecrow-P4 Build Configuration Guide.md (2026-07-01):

# Elecrow P4 Development Board Build Configuration Guide

## 📋 How to Ensure the elecrow-p4-board Configuration Is Used During Build

### Method 1: Select the Board via menuconfig (Recommended)

This is the standard approach—choose the development board through the graphical configuration menu:

```bash
# 1. Set the build target to ESP32-P4
idf.py set-target esp32p4

# 2. Open the configuration menu
idf.py menuconfig

# 3. Navigate in the menu:
#    Xiaozhi Assistant → Board Type → Elecrow P4 Board
#    Press Space to select, then save and exit

# 4. Build
idf.py build

```

**Menu path**
```
Xiaozhi Assistant
  └─ Board Type
      └─ [*] Elecrow P4 Board  ← Select this
```

### Method 2: Use the release.py Script (Easiest)

This project-provided automation script configures the board for you:

```bash
python scripts/release.py elecrow-p4-board
```

This script will:
- Automatically set the target chip to ESP32-P4
- Automatically configure the development board type
- Automatically build and package the firmware

### Method 3: Manually Edit sdkconfig (Advanced)

If you're comfortable with configuration files, you can edit `sdkconfig` directly:

```bash
# 1. Set the build target
idf.py set-target esp32p4

# 2. Edit the sdkconfig file, add or modify:
CONFIG_BOARD_TYPE_ELECROW_P4_BOARD=y

# 3. Build
idf.py build
```

## 🔍 How to Verify the Correct Board Configuration Is Being Used

### Method 1: Check Build Output

During compilation, you will see output like this:

```
-- Found BOARD_TYPE: elecrow-p4-board
-- Found BOARD_NAME: elecrow-p4-board
```

### Method 2: Check Build Commands

During compilation, check the macro definitions in the build commands:

```bash
idf.py build -v  # Verbose output mode
```

You should see:
```
-DBOARD_TYPE="elecrow-p4-board"
-DBOARD_NAME="elecrow-p4-board"
```

### Method 3: Check Compiled Files

After compilation, check if the `build/main/` directory contains your board files:

```bash
# You should see these files being compiled:
# - boards/elecrow-p4-board/elecrow_board.cc
# - boards/elecrow-p4-board/config.h (included via macro definition)
```

### Method 4: Check sdkconfig File

After compilation, check the `sdkconfig` file:

```bash
grep BOARD_TYPE sdkconfig
```

You should see:
```
CONFIG_BOARD_TYPE_ELECROW_P4_BOARD=y
```

## ⚠️ Important Notes

### 1. Confirm Board Type Before Each Build

If you have previously compiled for another board, the `sdkconfig` may still contain the previous configuration. It is recommended to:

```bash
# Clean previous configuration
idf.py fullclean

# Reset the target
idf.py set-target esp32p4

# Reconfigure the board
idf.py menuconfig
```

### 2. Ensure Directory Name Is Correct

The board directory name must match the `name` field in `config.json`:
- Directory name: `main/boards/elecrow-p4-board/`
- Name in config.json: `"elecrow-p4-board"`

### 3. Ensure Files Exist

Before compilation, confirm the following files exist:
- ✅ `main/boards/elecrow-p4-board/config.h`
- ✅ `main/boards/elecrow-p4-board/elecrow_board.cc`
- ✅ `main/boards/elecrow-p4-board/config.json`

## 🚀 Quick Start

### First Build

```bash
# 1. Clean (can be skipped for the first time)
idf.py fullclean

# 2. Set target chip
idf.py set-target esp32p4

# 3. Configure the board
idf.py menuconfig
# Select: Xiaozhi Assistant → Board Type → Elecrow P4 Board

# 4. Build
idf.py build

# 5. Flash (after connecting the device)
idf.py flash monitor
```

### Subsequent Builds

If already configured, you can build directly:

```bash
idf.py build
```

## 📝 Configuration File Description

### sdkconfig File

After compilation, the `sdkconfig` file will be generated in the project root directory, containing:

```ini
# Board type configuration
CONFIG_BOARD_TYPE_ELECROW_P4_BOARD=y

# Other configurations...
CONFIG_IDF_TARGET="esp32p4"
CONFIG_ESPTOOLPY_FLASHSIZE_16MB=y
```

### build/compile_commands.json

After compilation, `build/compile_commands.json` will be generated. You can check the compilation commands to confirm the correct macro definitions are being used.

## 🔧 Common Issues

### Q1: Build Error - Board Files Not Found?

**A:** Check:
1. Is the directory name correct: `main/boards/elecrow-p4-board/`
2. Is the file name correct: `elecrow_board.cc`
3. Is the correct board selected in menuconfig

### Q2: Build Uses Configuration from Another Board?

**A:** 
1. Run `idf.py fullclean` to clean
2. Run `idf.py menuconfig` again to select the board
3. Confirm that `sdkconfig` only contains `CONFIG_BOARD_TYPE_ELECROW_P4_BOARD=y`

### Q3: How to Confirm the Currently Configured Board?

**A:** 
```bash
# Check sdkconfig
grep BOARD_TYPE sdkconfig

# Or check build output
idf.py build 2>&1 | grep BOARD_TYPE
```

## ✅ Checklist

Before compilation, confirm:

- [ ] `idf.py set-target esp32p4` has been run
- [ ] "Elecrow P4 Board" has been selected in menuconfig
- [ ] `sdkconfig` contains `CONFIG_BOARD_TYPE_ELECROW_P4_BOARD=y`
- [ ] All configuration files exist (config.h, elecrow_board.cc, config.json)
- [ ] Flash size is correctly configured (currently 16MB)

---

**Now you can safely compile! The elecrow-p4-board configuration will be used automatically during compilation.**

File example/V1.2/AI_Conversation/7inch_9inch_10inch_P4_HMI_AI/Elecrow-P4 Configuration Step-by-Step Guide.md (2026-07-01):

# Elecrow P4 Board Configuration Guide

## 📋 Step 1: Extract Information from Your Working Code

You mentioned having working code, which is the most important reference! Please follow these steps to extract the information:

### 🔍 Information Checklist

#### 1. **Audio-related Pins** (Search for "I2S" or "GPIO" in your code)

Please find the following pin definitions:
- **MCLK** (Master Clock Pin)
- **BCLK** (Bit Clock Pin)
- **WS/LRCK** (Word Select/Left Right Channel Clock)
- **DIN/SDIN** (Data Input, Microphone)
- **DOUT/SDOUT** (Data Output, Speaker)

**In your code it might look like this:**
```c
#define I2S_MCLK_PIN GPIO_NUM_13
#define I2S_BCLK_PIN GPIO_NUM_12
// ... etc
```

#### 2. **I2C Pins** (Search for "I2C" or "SDA"/"SCL")

Find:
- **SDA** (Data Line)
- **SCL** (Clock Line)

#### 3. **Audio Codec Model** (Search for "ES8311", "ES8374", "ES8388", etc.)

Confirm your codec model, common ones include:
- ES8311
- ES8374
- ES8388
- ES8389

#### 4. **Button Pins** (Search for "BUTTON" or "BOOT")

Find the GPIO number for the boot button or function button

#### 5. **Display Information**

Find:
- **Resolution** (Width and Height, e.g., 800x1280)
- **Display Driver Chip** (e.g., JD9365, ST7703, etc.)
- **MIPI DSI Channel Count** (Usually 2 or 4)
- **DPI Clock Frequency** (e.g., 80MHz)

#### 6. **Flash Size**

Confirm whether your board's Flash is 4MB, 8MB, or 16MB

---

## 📝 Step 2: Modify the config.h File

Open `main/boards/elecrow-p4-board/config.h` and modify according to the information you extracted:

### Example Modification:

Assuming you found from your code:
- MCLK = GPIO_NUM_15
- BCLK = GPIO_NUM_14
- WS = GPIO_NUM_13
- DIN = GPIO_NUM_12
- DOUT = GPIO_NUM_11
- SDA = GPIO_NUM_6
- SCL = GPIO_NUM_7
- Button = GPIO_NUM_0
- Display = 720x720
- Codec = ES8311

**The modified config.h should be:**

```c
// Audio pins
#define AUDIO_I2S_GPIO_MCLK GPIO_NUM_15  // Value found from your code
#define AUDIO_I2S_GPIO_WS   GPIO_NUM_13  // Value found from your code
#define AUDIO_I2S_GPIO_BCLK GPIO_NUM_14  // Value found from your code
#define AUDIO_I2S_GPIO_DIN  GPIO_NUM_12  // Value found from your code
#define AUDIO_I2S_GPIO_DOUT GPIO_NUM_11  // Value found from your code

// I2C pins
#define AUDIO_CODEC_I2C_SDA_PIN  GPIO_NUM_6   // Value found from your code
#define AUDIO_CODEC_I2C_SCL_PIN GPIO_NUM_7   // Value found from your code

// Button
#define BOOT_BUTTON_GPIO GPIO_NUM_0  // Value found from your code

// Display resolution
#define DISPLAY_WIDTH 720   // Value found from your code
#define DISPLAY_HEIGHT 720  // Value found from your code
```

---

## 📝 Step 3: Modify the config.json File

Open `main/boards/elecrow-p4-board/config.json` and modify according to your Flash size:

### If Flash is 4MB:
```json
{
    "target": "esp32p4",
    "builds": [
        {
            "name": "elecrow-p4-board",
            "sdkconfig_append": [
                "CONFIG_IDF_TARGET=\"esp32p4\"",
                "CONFIG_ESPTOOLPY_FLASHSIZE_4MB=y",
                "CONFIG_PARTITION_TABLE_CUSTOM_FILENAME=\"partitions/v2/4m.csv\""
            ]
        }
    ]
}
```

### If Flash is 8MB:
```json
{
    "target": "esp32p4",
    "builds": [
        {
            "name": "elecrow-p4-board",
            "sdkconfig_append": [
                "CONFIG_IDF_TARGET=\"esp32p4\"",
                "CONFIG_ESPTOOLPY_FLASHSIZE_8MB=y",
                "CONFIG_PARTITION_TABLE_CUSTOM_FILENAME=\"partitions/v2/8m.csv\""
            ]
        }
    ]
}
```

### If Flash is 16MB (default):
Keep the current configuration unchanged

---

## 📝 Step 4: Modify the elecrow_board.cc File

### 4.1 Modify Codec Type

If your codec is **not ES8311**, you need to modify:

**Find this line:**
```cpp
#include "codecs/es8311_audio_codec.h"
```

**Modify according to your codec:**
- ES8374: `#include "codecs/es8374_audio_codec.h"`
- ES8388: `#include "codecs/es8388_audio_codec.h"`
- ES8389: `#include "codecs/es8389_audio_codec.h"`

**Then find the GetAudioCodec() function and modify:**
```cpp
// If ES8374
static Es8374AudioCodec audio_codec(...);

// If ES8388
static Es8388AudioCodec audio_codec(...);
```

### 4.2 Modify Display Driver Chip

If your display driver chip is **not JD9365**, you need to modify:

**Find this line:**
```cpp
#include "esp_lcd_jd9365_10_1.h"
```

**Modify according to your chip:**
- ST7703: `#include "esp_lcd_st7703.h"`
- Other chips: Check the header file used in your code

**Then find the relevant code in the InitializeLCD() function and modify:**
```cpp
// If ST7703
esp_lcd_dsi_bus_config_t bus_config = ST7703_PANEL_BUS_DSI_2CH_CONFIG();
esp_lcd_dbi_io_config_t dbi_config = ST7703_PANEL_IO_DBI_CONFIG();
esp_lcd_new_panel_st7703(io, &lcd_dev_config, &disp_panel);
```

### 4.3 Modify DPI Clock Frequency

In the `InitializeLCD()` function, find:
```cpp
.dpi_clock_freq_mhz = 80,  // Clock frequency
```

Modify this value according to your display specifications (common values: 46, 80, 100, etc.)

### 4.4 Touchscreen Support

If your board **does not support touchscreen**, comment out in the constructor:
```cpp
// InitializeTouch();  // Already commented, if touchscreen is supported, uncomment
```

If touchscreen is supported but the touch chip is not GT911, you need to modify the touch initialization code.

---

## 🧪 Step 5: Test Compilation

### 5.1 Set Build Target

```bash
idf.py set-target esp32p4
```

### 5.2 Build the Project

```bash
idf.py build
```

### 5.3 Check Compilation Errors

If there are compilation errors, please:
1. **Read the error messages carefully**
2. **Check if all pin numbers are correct**
3. **Check if the codec and display driver match**

---

## 🔧 Troubleshooting Common Issues

### Issue 1: Header File Not Found

**Error Example:**
```
fatal error: codecs/es8311_audio_codec.h: No such file or directory
```

**Solution:**
- Check if the codec type is correct
- Check which codecs are available in the `main/audio/codecs/` directory

### Issue 2: GPIO Definition Error

**Error Example:**
```
GPIO_NUM_XX is not declared
```

**Solution:**
- Check if the GPIO number is within the valid range for ESP32-P4
- Confirm if the GPIO number is correct

### Issue 3: Display Not Showing

**Possible Causes:**
- Display driver chip mismatch
- Incorrect DPI clock frequency
- Incorrect MIPI DSI channel count
- Incorrect resolution configuration

### Issue 4: No Audio Output

**Possible Causes:**
- Incorrect I2S pin configuration
- Incorrect codec I2C address
- Incorrect PA enable pin configuration

---

## 📞 Information to Provide When Seeking Help

If you encounter problems, please provide:

1. **Your board model and specifications**
2. **Pin configuration extracted from your working code**
3. **Compilation error messages (complete output)**
4. **Your hardware configuration:**
   - Codec model
   - Display model and resolution
   - Flash size
   - Whether touchscreen is supported

---

## ✅ Checklist

Before flashing, please confirm:

- [ ] All GPIO pin numbers have been extracted from your code and modified
- [ ] Codec type has been correctly configured
- [ ] Display driver chip has been correctly configured
- [ ] Display resolution has been correctly configured
- [ ] Flash size has been correctly configured
- [ ] Compilation passes without errors
- [ ] Touchscreen configuration (if not needed, has been commented out)

---

## 🚀 Next Steps

After configuration is complete, use the following commands to compile and flash:

```bash
# Method 1: Using script (recommended)
python scripts/release.py elecrow-p4-board

# Method 2: Manual compilation
idf.py set-target esp32p4
idf.py build
idf.py flash monitor
```

Good luck with your configuration! If you have any questions, feel free to ask.

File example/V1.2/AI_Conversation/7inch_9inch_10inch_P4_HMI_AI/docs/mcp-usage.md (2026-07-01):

# MCP Protocol IoT Control Usage Guide

> This document introduces how to implement IoT control for ESP32 devices based on the MCP protocol. For detailed protocol flow, please refer to [`mcp-protocol.md`](./mcp-protocol.md).

## Introduction

MCP (Model Context Protocol) is a next-generation protocol recommended for IoT control. It discovers and invokes "tools" between the backend and devices through standard JSON-RPC 2.0 format, enabling flexible device control.

## Typical Usage Flow

1. After device startup, establish a connection with the backend through the underlying protocol (such as WebSocket/MQTT).
2. The backend initializes the session through the MCP protocol's `initialize` method.
3. The backend obtains all tools (functionalities) supported by the device and their parameter descriptions through `tools/list`.
4. The backend invokes specific tools through `tools/call` to achieve device control.

For detailed protocol format and interactions, please see [`mcp-protocol.md`](./mcp-protocol.md).

## Device-Side Tool Registration Method

Devices register "tools" that can be invoked by the backend through the `McpServer::AddTool` method. Its common function signature is as follows:

```cpp
void AddTool(
    const std::string& name,           // Tool name, recommended to be unique and hierarchical, e.g., self.dog.forward
    const std::string& description,    // Tool description, concise explanation of functionality for LLM understanding
    const PropertyList& properties,    // Input parameter list (can be empty), supports types: bool, int, string
    std::function<ReturnValue(const PropertyList&)> callback // Callback implementation when tool is invoked
);
```
- name: Unique identifier for the tool, recommended to use "module.function" naming style.
- description: Natural language description for AI/user understanding.
- properties: Parameter list, supports types bool, int, string, can specify ranges and default values.
- callback: Actual execution logic when receiving invocation requests, return value can be bool/int/string.

## Typical Registration Example (ESP-Hi as Example)

```cpp
void InitializeTools() {
    auto& mcp_server = McpServer::GetInstance();
    // Example 1: No parameters, control robot forward movement
    mcp_server.AddTool("self.dog.forward", "Robot moves forward", PropertyList(), [this](const PropertyList&) -> ReturnValue {
        servo_dog_ctrl_send(DOG_STATE_FORWARD, NULL);
        return true;
    });
    // Example 2: With parameters, set RGB light color
    mcp_server.AddTool("self.light.set_rgb", "Set RGB color", PropertyList({
        Property("r", kPropertyTypeInteger, 0, 255),
        Property("g", kPropertyTypeInteger, 0, 255),
        Property("b", kPropertyTypeInteger, 0, 255)
    }), [this](const PropertyList& properties) -> ReturnValue {
        int r = properties["r"].value<int>();
        int g = properties["g"].value<int>();
        int b = properties["b"].value<int>();
        led_on_ = true;
        SetLedColor(r, g, b);
        return true;
    });
}
```

## Common Tool Invocation JSON-RPC Examples

### 1. Get Tool List
```json
{
  "jsonrpc": "2.0",
  "method": "tools/list",
  "params": { "cursor": "" },
  "id": 1
}
```

### 2. Control Chassis Forward
```json
{
  "jsonrpc": "2.0",
  "method": "tools/call",
  "params": {
    "name": "self.chassis.go_forward",
    "arguments": {}
  },
  "id": 2
}
```

### 3. Switch Light Mode
```json
{
  "jsonrpc": "2.0",
  "method": "tools/call",
  "params": {
    "name": "self.chassis.switch_light_mode",
    "arguments": { "light_mode": 3 }
  },
  "id": 3
}
```

### 4. Camera Flip
```json
{
  "jsonrpc": "2.0",
  "method": "tools/call",
  "params": {
    "name": "self.camera.set_camera_flipped",
    "arguments": {}
  },
  "id": 4
}
```

## Notes
- Tool names, parameters, and return values should be based on the device-side `AddTool` registration.
- It is recommended that all new projects uniformly adopt the MCP protocol for IoT control.
- For detailed protocol and advanced usage, please refer to [`mcp-protocol.md`](./mcp-protocol.md).

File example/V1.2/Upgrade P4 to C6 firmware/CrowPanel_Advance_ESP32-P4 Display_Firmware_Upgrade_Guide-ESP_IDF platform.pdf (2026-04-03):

## Tutorial on Upgrading the C6 Firmware

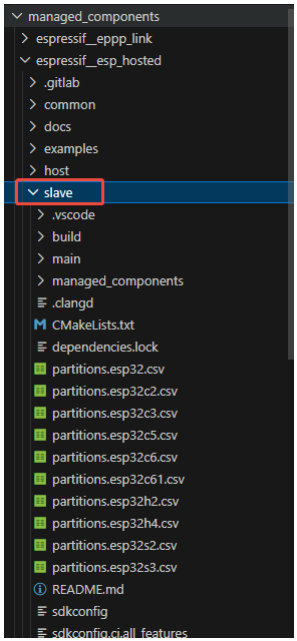
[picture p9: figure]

After compilation, a default network_adapter.bin file is generated in the build folder.

## via P4

First, select a version of the Hosted component. Here, we’ll choose version V2.12.3. The “slave” folder within the component contains the slave project. After selecting the ESP32-C6 chip, you can proceed to compile.

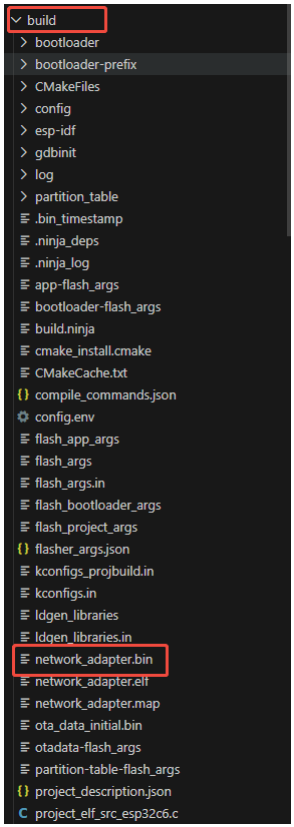
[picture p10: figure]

The 'host_performs_slave_ota' folder in the Hosted component is the OTA update project for the P4.

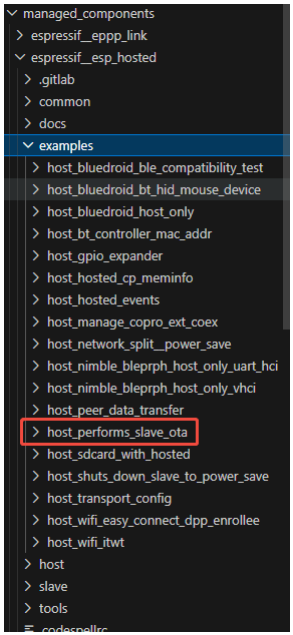
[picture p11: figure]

Add the following content to the 'sdkconfig.defaults' folder in the 'host_performs_slave_ota' project. Compile after modifying the default Hosted configuration. If the 'sdkconfig' file has already been generated, you can also make changes in 'menuconfig'.

# P4 chip version select

CONFIG_ESP32P4_SELECTS_REV_LESS_V3=y

# Host Slave OTA config

CONFIG_OTA_METHOD_LITTLEFS=y

CONFIG_ESP_HOSTED_PRIV_SDIO_PIN_CLK_SLOT_1=18 CONFIG_ESP_HOSTED_PRIV_SDIO_PIN_D0_SLOT_1=17 CONFIG_ESP_HOSTED_PRIV_SDIO_PIN_D1_4BIT_BUS_SLOT _1=16
CONFIG_ESP_HOSTED_PRIV_SDIO_PIN_D2_4BIT_BUS_SLOT _1=15
CONFIG_ESP_HOSTED_PRIV_SDIO_PIN_D3_4BIT_BUS_SLOT _1=14
CONFIG_ESP_HOSTED_SDIO_GPIO_RESET_SLAVE=32 5inch V1.0
CONFIG_ESP_HOSTED_SDIO_SLOT_1=y CONFIG_ESP_HOSTED_SDIO_4_BIT_BUS=y

Pin assignments vary by hardware version # Hosted slave config

7、9、10.1inch V1.0

CONFIG_ESP_HOSTED_SDIO_1_BIT_BUS=y CONFIG_ESP_HOSTED_SDIO_BUS_WIDTH=1 CONFIG_ESP_HOSTED_SDIO_CLOCK_FREQ_KHZ=40000 CONFIG_ESP_HOSTED_PRIV_SDIO_PIN_CMD_SLOT_1=19 CONFIG_ESP_HOSTED_PRIV_SDIO_PIN_CLK_SLOT_1=18 CONFIG_ESP_HOSTED_PRIV_SDIO_PIN_D0_SLOT_1=14 CONFIG_ESP_HOSTED_PRIV_SDIO_PIN_D1_1BIT_BUS_SLOT _1=15
CONFIG_ESP_HOSTED_SDIO_GPIO_RESET_SLAVE=32

7、9、10.1inch V1.1

CONFIG_ESP_HOSTED_SDIO_SLOT_1=y CONFIG_ESP_HOSTED_SDIO_4_BIT_BUS=y CONFIG_ESP_HOSTED_SDIO_CLOCK_FREQ_KHZ=40000 CONFIG_ESP_HOSTED_PRIV_SDIO_PIN_CMD_SLOT_1=19

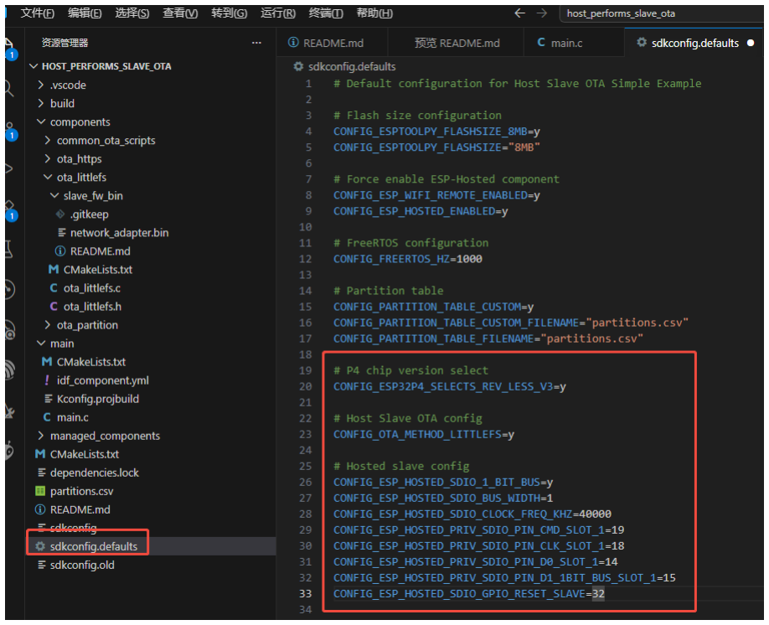
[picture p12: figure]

Place the network_adapter.bin firmware generated by the slave
project | into | the | corresponding | folder | in | the
host_performs_slave_ota project.

CONFIG_ESP_HOSTED_SDIO_CLOCK_FREQ_KHZ=40000 CONFIG_ESP_HOSTED_PRIV_SDIO_PIN_CMD_SLOT_1=54 CONFIG_ESP_HOSTED_PRIV_SDIO_PIN_CLK_SLOT_1=53 CONFIG_ESP_HOSTED_PRIV_SDIO_PIN_D0_SLOT_1=52 CONFIG_ESP_HOSTED_PRIV_SDIO_PIN_D1_4BIT_BUS_SLOT _1=51
CONFIG_ESP_HOSTED_PRIV_SDIO_PIN_D2_4BIT_BUS_SLOT _1=50
CONFIG_ESP_HOSTED_PRIV_SDIO_PIN_D3_4BIT_BUS_SLOT _1=49
CONFIG_ESP_HOSTED_SDIO_GPIO_RESET_SLAVE=20

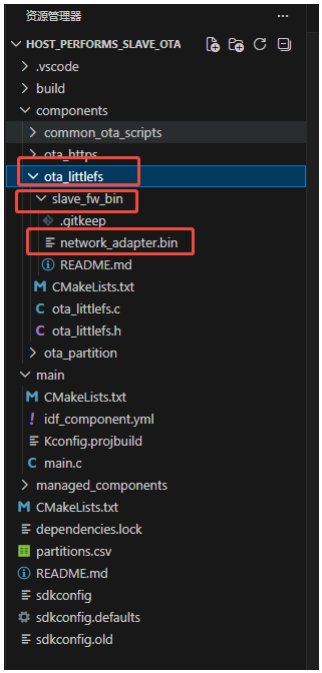
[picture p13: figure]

After | that, | select | the | ESP32-P4 | chip, | compile | the
host_performs_slave_ota project, and upload it to the ESP32-P4 Advance Board. Once the program runs, it will perform an OTA update of the C6 firmware.

Regarding the 1-bit and 4-bit options:

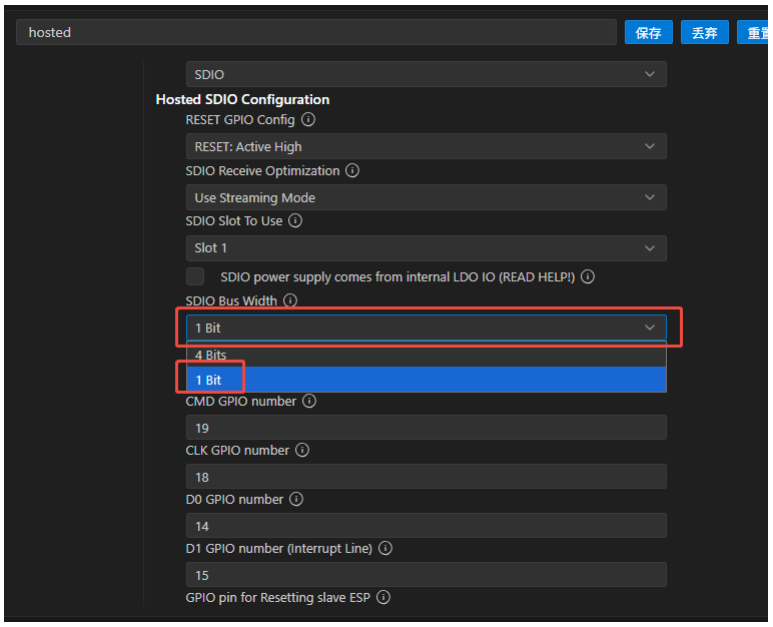
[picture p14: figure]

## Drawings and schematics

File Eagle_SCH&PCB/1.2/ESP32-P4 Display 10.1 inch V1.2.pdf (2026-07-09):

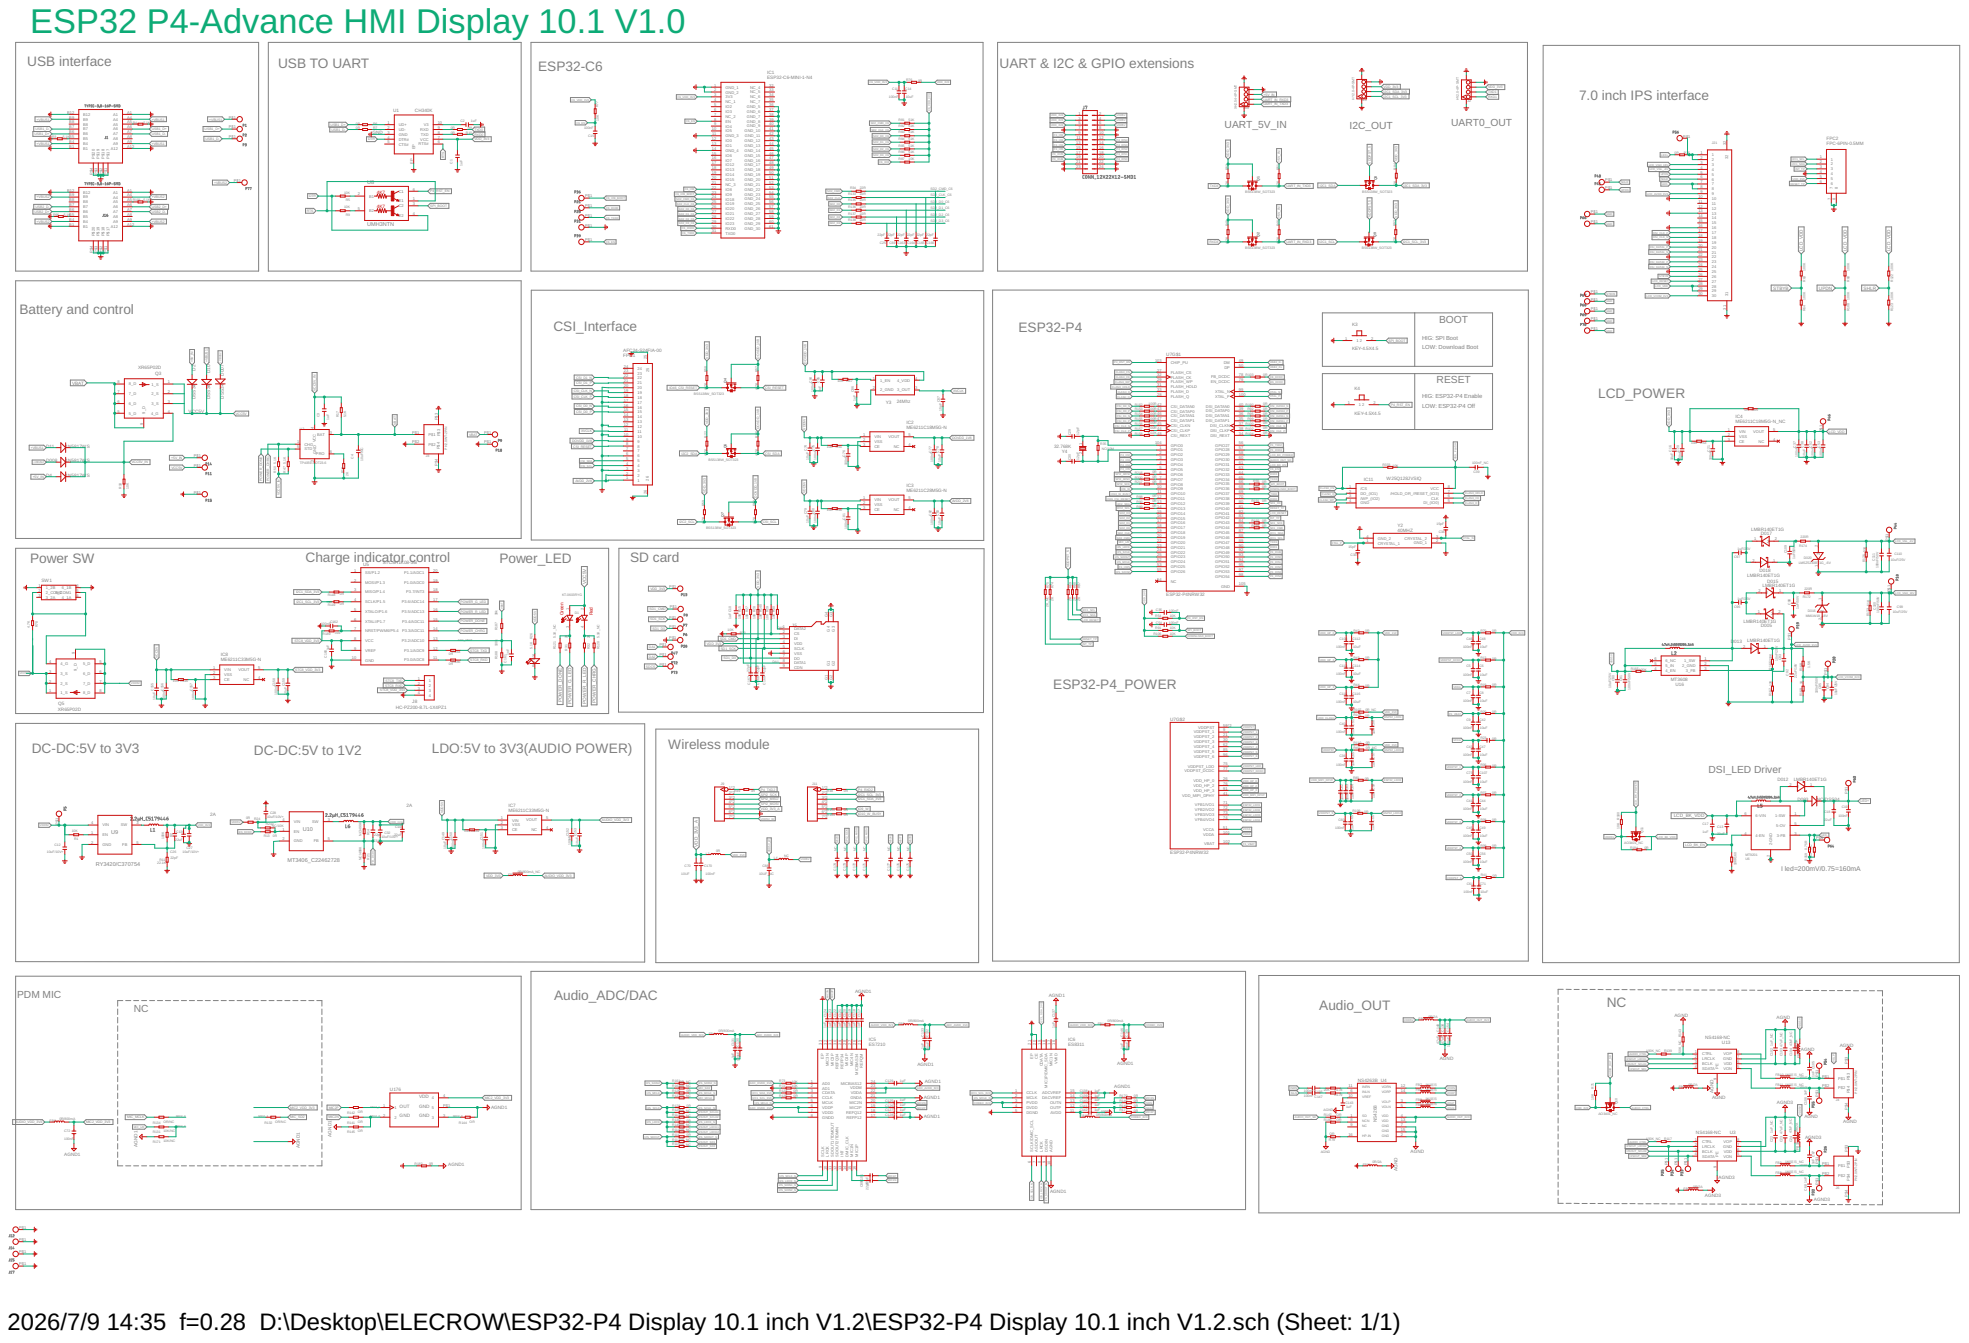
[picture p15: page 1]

HIG: SPI Boot LOW: Download Boot HIG: ESP32-P4 Enable

LDO:5V to 3V3(AUDIO POWER)

2026/7/9 14:35 f=0.28 D:\Desktop\ELECROW\ESP32-P4 Display 10.1 inch V1.2\ESP32-P4 Display 10.1 inch V1.2.sch (Sheet: 1/1)

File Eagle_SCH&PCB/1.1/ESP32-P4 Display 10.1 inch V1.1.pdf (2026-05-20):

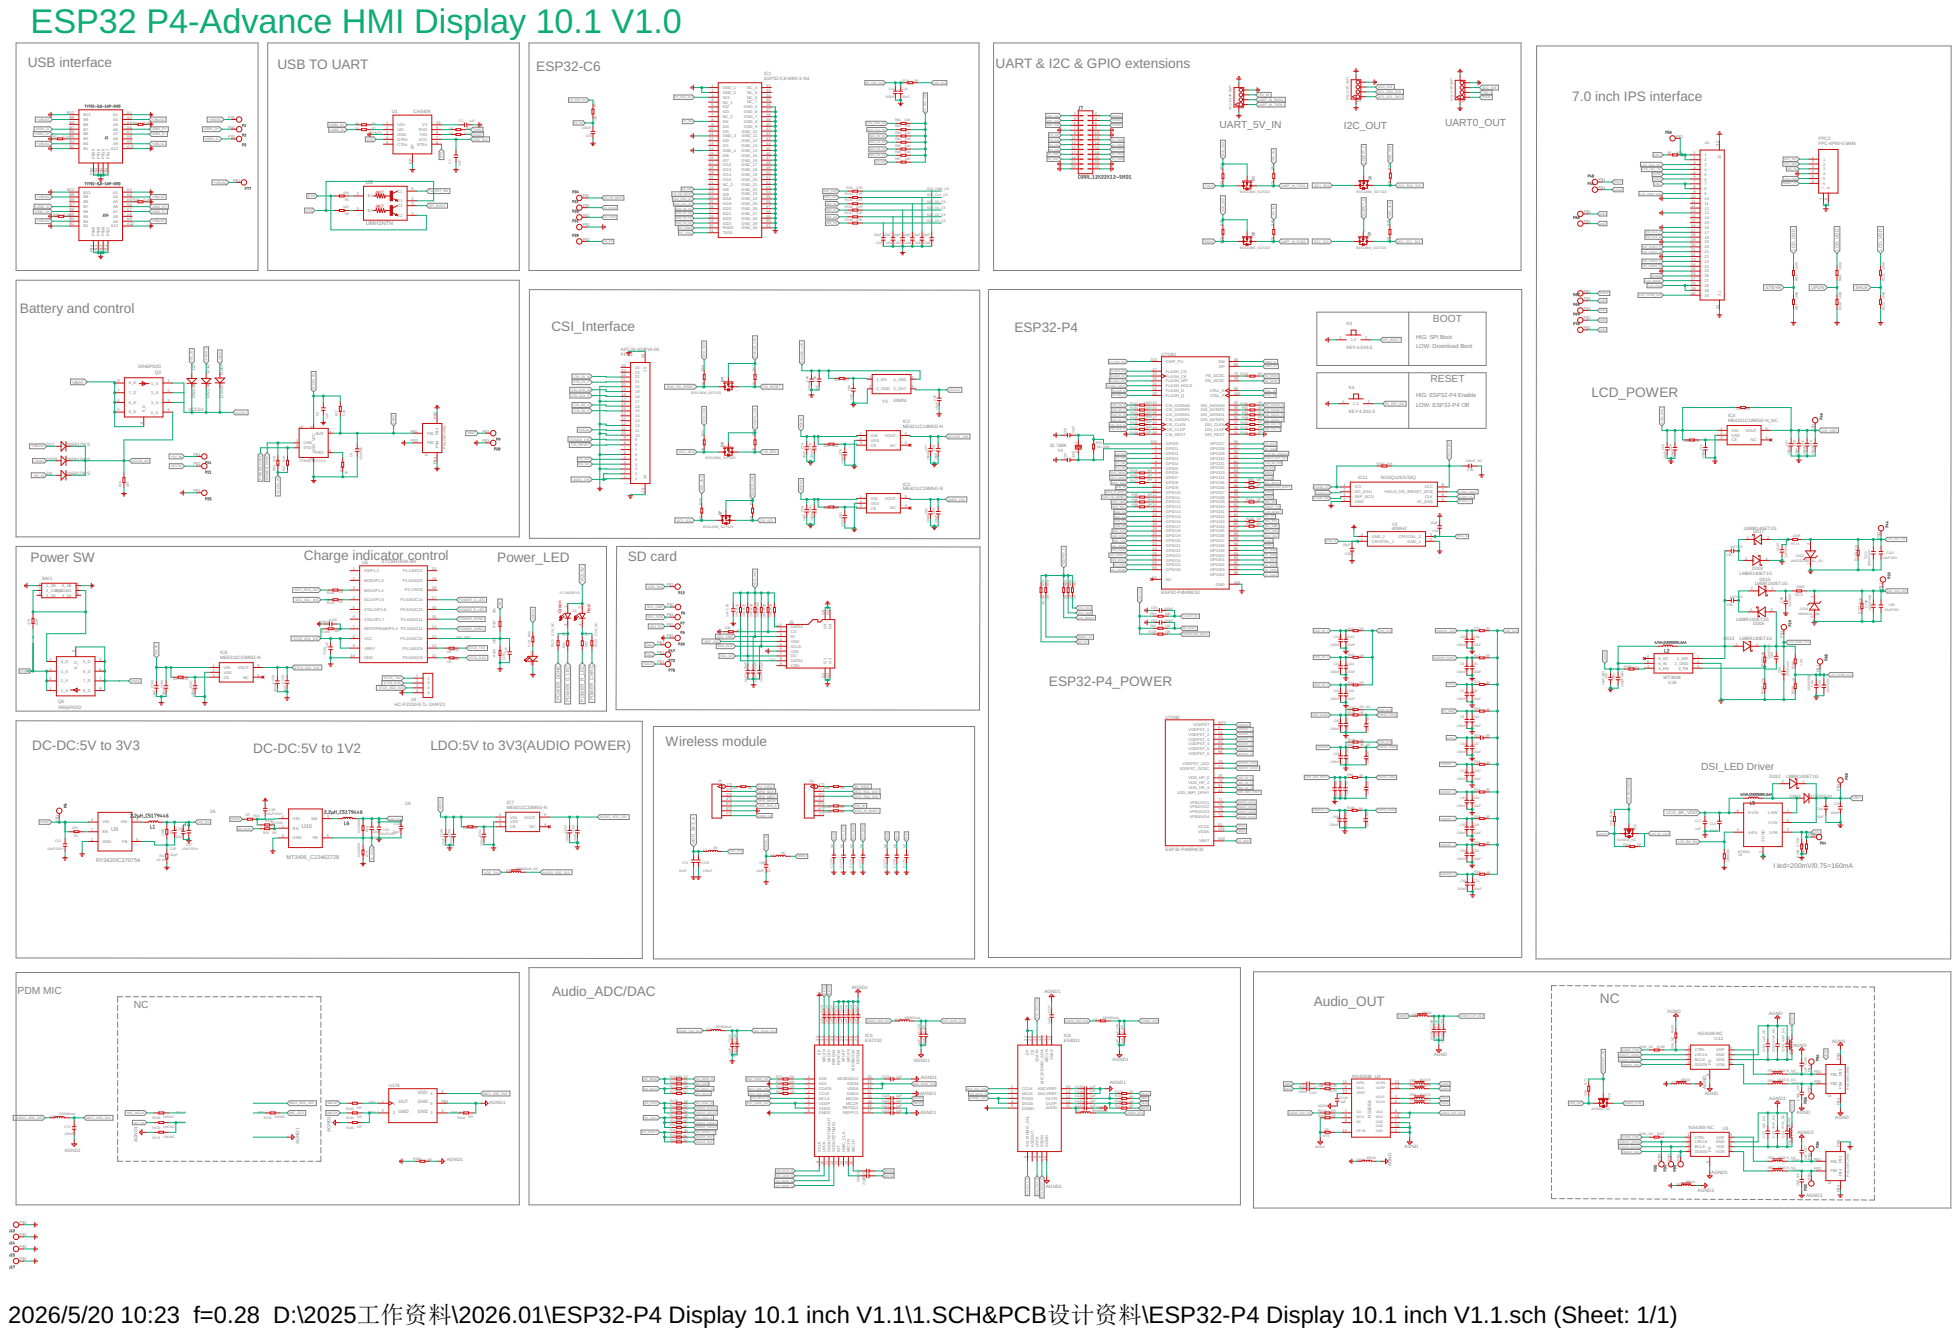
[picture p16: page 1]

HIG: SPI Boot LOW: Download Boot HIG: ESP32-P4 Enable

LDO:5V to 3V3(AUDIO POWER)

2026/5/20 10:23 f=0.28 D:\2025工作资料\2026.01\ESP32-P4 Display 10.1 inch V1.1\1.SCH&PCB设计资料\ESP32-P4 Display 10.1 inch V1.1.sch (Sheet: 1/1)

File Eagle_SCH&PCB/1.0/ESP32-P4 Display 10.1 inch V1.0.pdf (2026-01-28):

UART_5V_IN | I2C_OUT | UART0_OUT

### CH340K

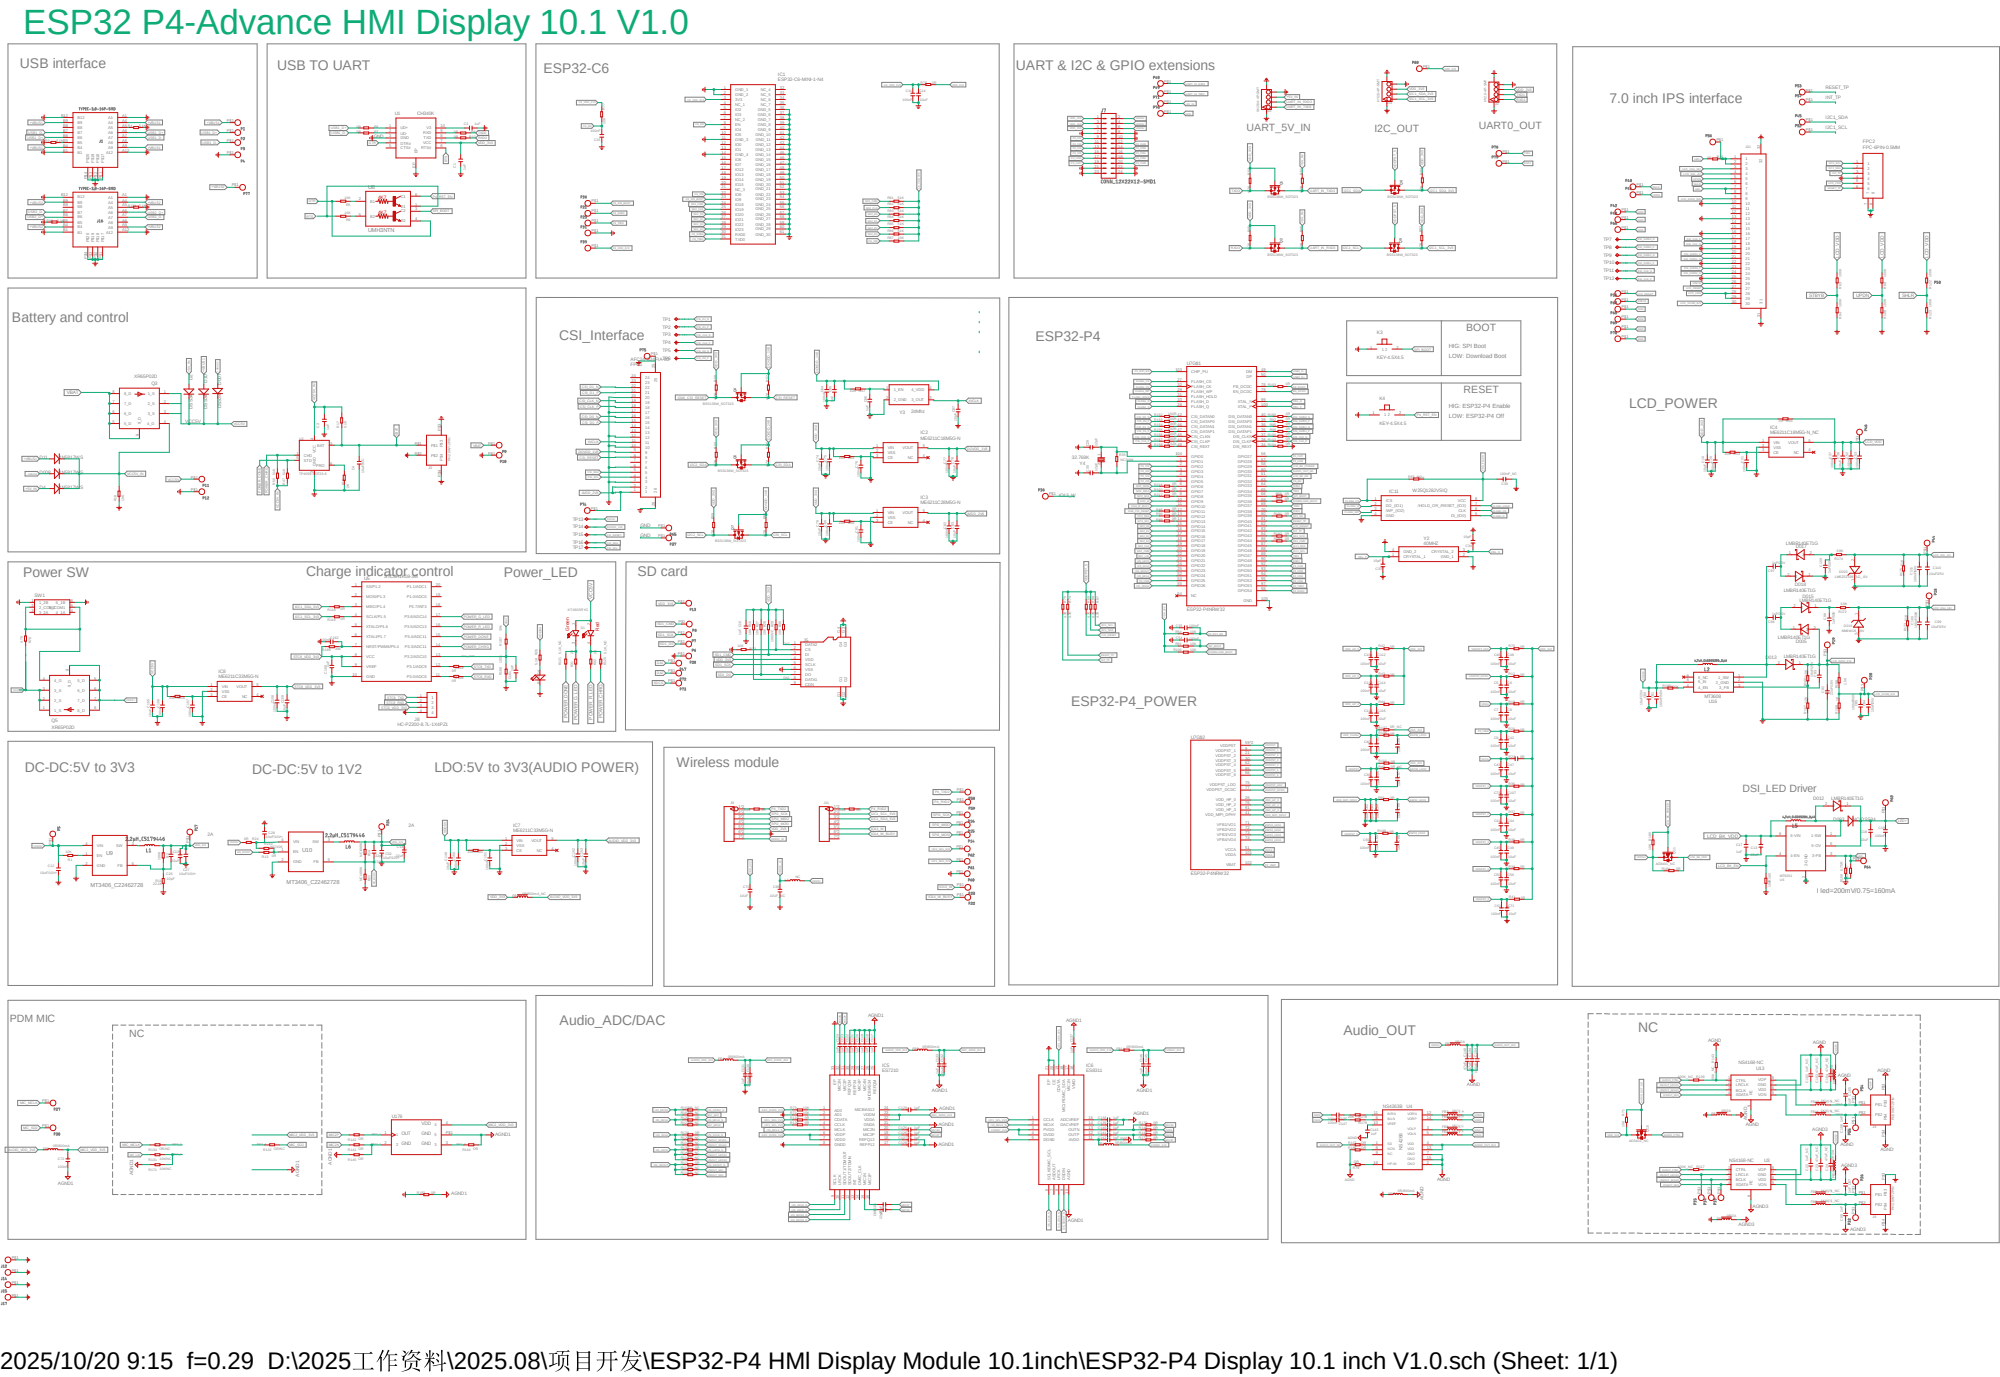
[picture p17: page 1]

LDO:5V to 3V3(AUDIO POWER)

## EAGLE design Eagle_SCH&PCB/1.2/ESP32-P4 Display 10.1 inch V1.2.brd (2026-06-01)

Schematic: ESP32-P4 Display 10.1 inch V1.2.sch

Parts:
C1, C2, C3, C10, C17, C86, C143, C160: 1uF; 0603
C4: 10uF/NC; 0603
C5, C7, C9, C36, C40, C41, C43, C45, C46, C50, C60, C61, C63, C72, C73, C108, C113, C115, C130, C132, C145: 100nF; C0402
C6, C8, C42, C44, C47, C48, C49, C56, C71, C107, C112, C114, C116: 10uF; C0402
C11, C15, C19, C20, C21, C35, C37, C52, C53, C54, C75, C76, C77, C80, C81, C82, C84, C135, C147, C150, C151, C152, C154, C156, C157, C158, C162, C170: 100nF; 0603
C12, C27, C28, C32: 10uF/10V+; 0603
C13, C18: 22uF; C0805
C14, C16, C38, C74, C78, C79, C83, C149, C153, C155, C159: 10uF; 0603
C22, C102: 1uF_NC; 0603
C23, C24, C103, C104: 47uF_NC; 0603
C25, C69, C89, C101, C163, C164, C165, C166, C167, C168, C169: 22pF; C0402
C26, C31: 22pF; 0603
C29, C30: 12pF; C0402
C33, C34: 15pF; C0402
C39: 100nF_NC; C0402
C51, C55, C57, C58, C59, C64, C65, C66, C117, C118, C119, C120, C121, C122, C123, C124, C125, C126, C127, C128, C129, C131, C133, C137, C138, C139, C140, C141, C142, C146: 1uF; C0402
C62: 10nF; C0402
C67, C68, C85, C105, C106, C161: 1nF; 0603
C70: 10UF; 0603
C87: 15pF; 0603
C88: 10UF_NC; 0603
C90, C99, C110: 10uF/25V; 0603
C91, C100, C111: 100nF/50V; 0603
C92: 22uF/16V; C0805
C93: 10nF/25V; 0603
C94: 10uF/25V; C0402
C95: 100nF/50V; C0402
C96, C97: 1uF/25V; 0603
C98, C109: 1uF/50V; 0603
C134, C148: 47uF; 0603
C136, C144: 22uF; 0805
C171, C172, C173, C174, C175, C176, C177: NC; C0402
D1: KT-0603RYG; LED_KT-0603RYG
D2, D007, D10: DSS34; D_SOD123FL
D003: NC/DSS34; D_SOD123FL
D4, D008, D11: 1N5817WS; D_SOD323
D005, D012, D013, D015, D017, D018: LMBR140ET1G
D14: Red; LED0603
D016: MM1W18_18V; LMSZ5233BT1G
D020: LMSZ5233BT1G_-6V; LMSZ5233BT1G
FB2, FB3, FB10, FB11: 1K/磁珠_NC; L0603
FB4, FB5, FB6, FB13: 0R/800mA; L0402
FB7, FB8, FB9, FB12: 1K/磁珠; L0603
FB14: 0R/800mA; R0402
FB15, FB17, FB18, FB19, FB20: 0R/2A; L0603
FB16: 0R/800mA_NC; L0603
FB21: 0R/2A; L0805
FPC1: AFC24-S24FIA-00; FPC-SMD_P0.50-24P_QCHF-SM-H2.0
FPC2: FPC-6PIN-0.5MM
IC1: ESP32-C6-MINI-1-N4; ESP32C6MINI1N4
IC2: ME6211C18M5G-N; SOT95P282X145-5N
IC3: ME6211C28M5G-N; SOT95P282X145-5N
IC4: ME6211C18M5G-N_NC; SOT95P282X145-5N
IC5: ES7210; QFN40P400X400X80-33N
IC6: ES8311; QFN40P300X300X60-21N
IC7, IC8: ME6211C33M5G-N; SOT95P282X145-5N
IC11: W25Q128JVSIQ; SOIC127P790X216-8N
J1, J16: TYPEC-3.0-16P-SMD; USB-3.0TYPEC-SMD
J2, J13: HY2.0-4P-SMT; CONNECTOR_4P-SMD-2.0
J3, J4, J6: PH2.0WT-2PIN
J5: HOLDER-MICROSD-9P; 9P-SMD-W/-RING
J7: CONN_12X22X12-SMD1; 2X12-SMD1
J8: HC-PZ200-8.7L-1X4PZ1; TEST-PIN-4-2.0MM
J9, J11: HEADER-7P-18.28X2.5; H7-2.54-18.28X2.5X5MM
J10: XH2.54-4P-SMT; XH2.54-4P-SMD
J12, J14, J15, J17: THO-M3.25MM-HOLE; THO-M3.2*5MM-HOLE
J21: C23398852_30P_0.5MM_下接_FC-05A30P11H20
K3, K4: KEY-4.5X4.5; KEY-4.5X4.5-SMD
L1, L6: 2.2μH_C5179446; 1008(2520)
L2, L5: 4.7uH_C45385206_2.4A; 1008(2520)
L3: 0R; L0603
L4: NC; L0603
P1, P2, P3, P5, P6, P7, P8, P9, P10, P11, P13, P14, P15, P18, P19, P20, P21, P25, P26, P28, P31, P32, P33, P34, P35, P36, P39, P40, P41, P43, P44, P46, P47, P51, P54, P55, P56, P63, P64, P66, P67, P68, P69, P70, P72, P73, P77: TEST_PADPAD-1.5MM; TEST_PAD-1.5MM
Q1, Q2, Q4, Q6, Q7, Q8, Q9: BSS138W_SOT323; MOS_SOT323
Q3, Q5: XR65P02D; PDFN3333
Q10, Q11: AO3401_NC; PMOS_SOT23
R1, R5, R9, R18, R53, R54, R61, R66, R67, R71, R77, R87, R91, R106, R116, R160, R180, R181: 10K; R0603@1
R2, R165: 100K; R0603@1
R3, R4, R17, R26, R47, R50, R96, R101: 5.1K; R0603@1
R6, R7, R8, R10, R13, R24, R55, R60, R65, R76, R103, R118, R119, R164, R184, R186: 0R; R0603@1
R11: 22.1K; R0603
R12, R19, R20, R36, R37, R38, R39, R41, R42, R43, R44, R70, R80, R88, R89, R90, R92, R95, R99, R100, R102, R104, R105, R109, R110, R111, R124, R125, R126, R128, R130, R146, R148, R170, R177, R190, R191, R192, R193: 0R; R0402
R14, R21: NC/499K; R0603
R15, R27, R28, R29, R30, R33, R72, R73, R140, R333: 10K; R0402
R16, R31, R32, R69: 2K; R0603-SP
R22, R45, R46, R51, R52, R56, R57, R58, R59, R62, R78: 4.7K; R0603@1
R23: 0R; C0402
R25: 0R; R0603-SP
R34, R133, R135, R136, R137, R138: 22R; R0402
R35: NC/10M; R0402
R40, R107, R127, R161, R162: 0R_NC; R0402
R48, R49, R151, R194, R216, R217, R332: 0R; 0402
R63, R64, R68, R108, R122, R123: 100K; R0402
R74, R93, R94, R97, R98: 2K; R0603@1
R75: 2K_NC; R0603@1
R79, R147, R185: OR; R0603-SP
R81, R82, R83, R84, R85, R86: 51K; R0402
R112, R113, R114, R115, R129, R149: 0R_NC; R0603@1
R117, R139: 100K_NC; R0603@1
R120, R121: 5.1K_NC; R0603@1
R131, R171: 10K/NC; R0402
R132, R134: OR/NC; R0402
R141, R142, R144, R145: OR; R0402
R143: 50K_NC; R0603-SP
R152, R153, R154, R155, R156, R157: 100R; R0402
R158: 4.02K; R0402
R159: 0.75R; R0603-SP
R163: NC; R0603-SP
R166: 210K; R0603
R167: 12K; R0603
R168: 1.5K; R0402
R169: 1K; R0402
R172, R174: 220R; R0603
R173, R175: 51K; R0603@1
R178, R179: 20K; R0603
R182: 0R; R0805
R187, R189: 39k; R0603@1
R188: 100k; R0603@1
R210: NC/10K; R0603@1
SW1: switch_6pin; SWITCH_6PIN_2P
U1: CH340K; ESOP-10-EP-150MIL
U2: TP4059-SOT23-6; SOT23-6L
U3, U13: NS4168-NC; NS4168-ESOP-8
U4: NS4263B; SOP16
U5: STC8H1K08-36I; TSSOP20
U6: MT9201; COOPER_SOT23-6
U7: ESP32-P4NRW32; IC_ESP32-P4NRW32
U8: UMH3NTN; SOP65P210X100-6N
U9: RY3420/C370754; SOT95P280X145-5N
U10: MT3406_C22462728; SOT95P280X145-5N
U16: MT3608; SOT95P280X145-6N
U176: BRAIN1_LMA3526B3811; BRAIN1_MIC-SMD_5P-L3.5-W2.7
Y2: 40MHZ; X322540MPB4SI
Y3: 24Mhz; 24MHZ_1631-24003-BTKEYA
Y4: 32.768K; NORDIC_NRF_XTAL_3215_N

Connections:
3V3$: C2.2, U1.10 (V3)
+5V_IN: D2.+, D4.+, J10.3, P14.P$1, R46.1, R51.1
+VBUS1: D10.+, D11.+, J1.A4, J1.A9, J1.B4, J1.B9, P1.P$1
+VBUS2: D007.+, D008.+, J16.A4, J16.A9, J16.B4, J16.B9, P77.P$1
ADC_AVDD_3V3: C132.1, C133.2, FB5.2, IC5.22 (VDDA), IC5.23 (VDDM)
ADC_DVDD_3V3: C130.1, C131.2, FB4.2, IC5.6 (VDDP), IC5.7 (VDDD), R73.1
ADC_VBAT: C161.2, R187.2, R188.1, U5.13 (P3.2/ADC10)
AGND: C102.2, C103.2, C104.2, C105.1, C106.1, C134.1, C143.1, C148.1, C154.2, FB19.2, FB21.2, J4.P$3, J4.P$4, R79.2, R143.1, R185.1, U4.2, U4.7, U4.15, U13.7 (GND), U13.9 (PE)
AGND1: C72.1, C117.1, C118.1, C119.1, C120.1, C121.1, C122.1, C127.2, C128.2, C129.2, C132.2, C133.1, C137.1, C138.2, C139.2, C142.2, C145.2, C146.1, IC5.21 (GNDA), IC6.10 (AGND), R144.1, R145.2, R171.2, R182.2, U176.P$1 (5)
AGND3: C22.2, C23.2, C24.2, C67.1, C68.1, FB20.2, U3.7 (GND), U3.9 (PE)
AUDIO_CTRL: Q10.3 (D), R117.2, R139.2
AUDIO_OUT_3V3: C134.2, C148.2, C154.1, FB15.2, U4.4, U4.13
AUDIO_OUT_SD: Q10.1 (G), R71.1, R147.1, U7.60 (GPIO30)
AUDIO_VDD1: C102.1, C103.1, C104.1, FB17.1, U13.6 (VDD)
AUDIO_VDD2: C22.1, C23.1, C24.1, FB18.1, U3.6 (VDD)
AUDIO_VDD_3V3: C152.2, C153.2, FB4.1, FB5.1, FB6.1, FB14.1, FB16.2, IC7.5 (VOUT)
AVDD_2V8: C82.2, C83.2, FPC1.1, FPC1.2, IC3.5 (VOUT)
C6_EN: C15.1, IC1.8 (EN), P39.P$1, R77.1, U7.63 (GPIO32)
C6_IO8: IC1.22 (IO8), R87.2
C6_IO9_BOOT: IC1.23 (IO9), P36.P$1
C6_RXD0: IC1.30 (RXD0), P21.P$1
C6_TXD0: IC1.31 (TXD0), P25.P$1
C6_VDD_3V3: C11.1, C14.2, IC1.3 (3V3), R76.1, R77.2, R81.1, R82.1, R83.1, R84.1, R85.1, R86.1, R87.1
CODEC_3V3: C145.1, C146.2, FB13.2, FB14.2, IC6.3 (PVDD), IC6.4 (DVDD)
CSID0_P: R153.1, U7.43 (CSI_DATAP0)
CSI_CLK_N: FPC1.19, R156.2
CSI_CLK_P: FPC1.18, R157.2
CSI_D0_N: FPC1.16, R152.2
CSI_D0_P: FPC1.15, R153.2
CSI_D1_N: FPC1.22, R154.2
CSI_D1_P: FPC1.21, R155.2
CSI_RESET: FPC1.8, Q4.2 (S), R57.2
CSI_SCL: FPC1.4, Q7.2 (S), R62.2
CSI_SDA: FPC1.5, Q6.2 (S), R56.2
DA1: J5.8 (DATA1), P47.P$1, R15.1
DA2: J5.1 (DATA2), P72.P$1, R30.1
DOVDD_1V8: C77.2, C78.2, C84.2, C85.2, FPC1.9, IC2.5 (VOUT), Q4.1 (G), Q6.1 (G), Q7.1 (G), R56.1, R57.1, R62.1, R67.2, Y3.4 (4_VDD)
DOWNLOAD_BOOT: R60.1, R106.2
DSI_CLK_N: J21.18, R100.1
DSI_CLK_P: J21.17, R102.1
DSI_DATA0_N: J21.24, R190.1
DSI_DATA0_P: J21.23, R92.1
DSI_DATA1_N: J21.21, R95.1
DSI_DATA1_P: J21.20, R99.1
DTR: R5.2, U1.4 (DTR#), U8.4 (E2)
EN_DCDC: R13.2, U7.79 (EN_DCDC)
ESP32_LDO1: C58.1, R105.2, U7.71 (VFB1/VO1)
ESP32_LDO2: C57.1, R40.2, U7.72 (VFB2/VO2)
ESP32_LDO3: C59.1, R80.2, U7.73 (VFB3/VO3)
ESP32_LDO4: C66.1, R109.2, U7.74 (VFB4/VO4)
FB_DCDC: C31.1, R14.2, R21.1, R103.1, U10.5 (FB)
FLASH_CK: IC11.6 (CLK), U7.32 (FLASH_CK)
FLASH_CS: IC11.1 (/CS), R333.1, U7.27 (FLASH_CS)
FLASH_D: IC11.5 (DI_(IO0)), U7.33 (FLASH_D)
FLASH_HOLD: IC11.7 (/HOLD_OR_/RESET_(IO3)), U7.31 (FLASH_HOLD)
FLASH_Q: IC11.2 (DO_(IO1)), U7.28 (FLASH_Q)
FLASH_WP: IC11.3 (/WP_(IO2)), U7.29 (FLASH_WP)
GND: C1.1, C2.1, C3.1, C4.1, C5.2, C6.1, C7.2, C8.1, C9.2, C10.1, C11.2, C12.2, C13.2, C14.1, C15.2, C16.1, C17.1, C18.2, C19.2, C20.1, C21.1, C25.2, C27.1, C28.2, C29.2, C30.2, C32.1, C33.2, C34.1, C35.1, C36.2, C37.1, C38.1, C39.2, C40.2, C41.2, C42.1, C43.2, C44.1, C45.2, C46.2, C47.1, C48.1, C49.1, C50.2, C51.2, C52.1, C53.1, C54.1, C55.2, C56.1, C57.2, C58.2, C59.2, C60.2, C61.2, C62.2, C63.2, C64.2, C65.2, C66.2, C69.2, C70.2, C71.1, C73.2, C74.1, C75.1, C76.1, C77.1, C78.1, C79.1, C80.1, C81.1, C82.1, C83.1, C84.1, C85.1, C86.1, C87.1, C88.2, C90.2, C91.2, C92.2, C94.2, C95.2, C98.2, C99.2, C100.2, C107.1, C108.2, C109.2, C110.2, C111.2, C112.1, C113.2, C114.1, C115.2, C116.1, C130.2, C131.1, C136.1, C144.1, C149.1, C150.1, C151.1, C152.1, C153.1, C155.1, C156.1, C157.1, C158.1, C159.1, C160.1, C161.1, C162.1, C163.2, C164.2, C165.2, C166.2, C167.2, C168.2, C169.2, C170.2, C171.1, C172.1, C173.1, C174.1, C175.1, C176.1, C177.1, D14.-, D016.2, D018.1, D020.1, FB19.1, FB20.1, FB21.1, FPC1.3, FPC1.6, FPC1.10, FPC1.12, FPC1.17, FPC1.20, FPC1.25, FPC1.26, FPC2.4, FPC2.7, FPC2.8, IC1.1 (GND_1), IC1.2 (GND_2), IC1.11 (GND_3), IC1.14 (GND_4), IC1.36 (GND_5), IC1.37 (GND_6), IC1.38 (GND_7), IC1.39 (GND_8), IC1.40 (GND_9), IC1.41 (GND_10), IC1.42 (GND_11), IC1.43 (GND_12), IC1.44 (GND_13), IC1.45 (GND_14), IC1.46 (GND_15), IC1.47 (GND_16), IC1.48 (GND_17), IC1.49 (GND_18), IC1.50 (GND_19), IC1.51 (GND_20), IC1.52 (GND_21), IC1.53 (GND_22), IC1.54 (GND_23), IC1.55 (GND_24), IC1.56 (GND_25), IC1.57 (GND_26), IC1.58 (GND_27), IC1.59 (GND_28), IC1.60 (GND_29), IC1.61 (GND_30), IC2.2 (VSS), IC3.2 (VSS), IC4.2 (VSS), IC5.8 (GNDD), IC5.33 (EP), IC6.5 (DGND), IC6.20 (CE), IC6.21 (EP), IC7.2 (VSS), IC8.2 (VSS), IC11.4 (GND), J1.A1, J1.A12, J1.B1, J1.B12, J1.P$1, J1.P$2, J1.P$3, J1.P$4, J2.4, J2.SS1, J2.SS2, J3.P$2, J3.P$3, J3.P$4, J5.6 (VSS), J5.G1, J5.G2, J5.G3, J5.G4, J6.P$3, J6.P$4, J7.7, J7.8, J7.10, J7.21, J7.22, J7.23, J7.24, J8.4, J9.6, J9.6-6 (6), J10.4, J10.5 (SS1), J10.6 (SS2), J12.P$1, J13.4, J13.SS1, J13.SS2, J14.P$1, J15.P$1, J16.A1, J16.A12, J16.B1, J16.B12, J16.P$1, J16.P$2, J16.P$3, J16.P$4, J17.P$1, J21.10, J21.13, J21.16, J21.19, J21.22, J21.25, J21.31, J21.32, K3.1, K4.1, P10.P$1, P15.P$1, P28.P$1, P31.P$1, P43.P$1, P66.P$1, P67.P$1, P68.P$1, P69.P$1, P70.P$1, R3.1, R4.2, R11.2, R16.1, R18.1, R21.2, R33.2, R64.1, R72.1, R96.1, R101.2, R104.1, R108.1, R123.1, R158.2, R159.1, R160.2, R163.1, R167.1, R169.1, R173.1, R175.1, R182.1, R188.2, SW1.1 (1_2B), SW1.6 (6_1B), U1.3 (GND), U1.EP, U2.2 (GND), U5.10 (GND), U6.2 (2-GND), U7.105 (GND), U9.2 (GND), U10.2 (GND), U16.2 (2_GND), Y2.2 (GND_1), Y2.4 (GND_2), Y3.2 (2_GND)
I2C1_SCL: FPC2.1, Q9.2 (S), R97.2, U7.88 (GPIO46)
I2C1_SCL_3V3: IC6.1 (CCLK), J11.2, J11.2-2 (2), J13.1, Q9.3 (D), R93.2, R119.1, R125.1
I2C1_SDA: FPC2.2, Q8.2 (S), R98.2, U7.87 (GPIO45)
I2C1_SDA_3V3: IC6.19 (CDATA), J11.3, J11.3-3 (3), J13.2, Q8.3 (D), R94.2, R118.1, R124.1
I2C2_SCL: Q7.3 (D), R59.2, R89.2
I2C2_SDA: Q6.3 (D), R22.2, R90.2
I2SOUT_LRCK1: R149.2, U13.2 (LRCLK)
I2SOUT_LRCK2: P35.P$1, R114.2, U3.2 (LRCLK)
I2SOUT_SCLK1: R129.2, U13.3 (BCLK)
I2SOUT_SCLK2: P34.P$1, R113.2, U3.3 (BCLK)
I2SOUT_SD1: R112.2, U13.4 (SDATA)
I2SOUT_SD2: P33.P$1, R115.2, U3.4 (SDATA)
I2S_LRCK: R114.1, R130.1, R149.1, U7.23 (GPIO21)
I2S_LRCK_N: IC5.10 (LRCK), IC6.8 (LRCK), R130.2
I2S_MCLK: R126.1, R127.1, U7.52 (GPIO24)
I2S_MCLK_N: IC5.5 (MCLK), IC6.2 (MCLK), R126.2
I2S_SCLK: R113.1, R128.1, R129.1, U7.24 (GPIO22)
I2S_SCLK_N: IC5.9 (SCLK), IC6.6 (SCLK/DMIC_SCL), R128.2
I2S_SDIN1_N: IC5.11 (SDOUT1/TDMOUT)
I2S_SDIN2: R161.1, R162.1, U7.55 (GPIO26)
I2S_SDIN2_N: IC5.12 (SDOUT2/TDMIN), R161.2
I2S_SDOUT: R111.1, R112.1, R115.1, U7.25 (GPIO23)
I2S_SDOUT_N: IC6.9 (DSDIN), R111.2
INLN: C147.1, R148.2
INLN1: R179.1, U4.6
INRN: C135.1, R146.2
INRN1: R178.1, U4.11
INT_TP: FPC2.3, R75.2, U7.83 (GPIO42)
IO1: R89.1, U7.14 (GPIO13)
IO8: R217.1, U7.8 (GPIO8)
IO9_W: R151.2, U7.10 (GPIO9)
IO10_W_BUSY: R194.2, U7.11 (GPIO10)
IO46_CSI_RESET: Q4.3 (D), R58.2, R88.2
LCD_AVDD_9V6: C92.1, C93.1, D005.2, D013.1, J21.9, P19.P$1, R166.2, R168.2
LCD_BK_EN: R160.1, U6.4 (4-EN), U7.61 (GPIO31)
LCD_BK_POWER: Q11.1 (G), R180.1, U7.58 (GPIO29)
LCD_BK_VDD: C13.1, C17.2, L5.1, Q11.3 (D), R184.2, U6.6 (6-VIN)
LCD_RESET: J21.27, R69.2, U7.82 (GPIO41)
LCD_VCOM_3V3: C94.1, C95.1, J21.30, P20.P$1, R168.1, R169.2
LCD_VDD: C37.2, C38.2, C52.2, C53.2, IC4.5 (VOUT), J21.28, J21.29, P46.P$1, R63.2, R65.1, R68.2, R122.2
LCD_VGH_18V: C99.1, C100.1, D016.1, J21.3, P18.P$1, R172.1, R173.2
LCD_VGL_-6V: C110.1, C111.1, D020.2, J21.4, P44.P$1, R174.1, R175.2
LED+: C18.1, C19.1, D003.-, D012.1, P63.P$1, R25.1, U6.5 (5-OV)
LED-: J21.7, J21.8, P64.P$1, R159.2, R163.2, U6.3 (3-FB)
MIC1N: C89.2
MIC1P: C101.2
MIC2N: C125.2, R141.2
MIC2P: C126.2, R142.2
MIC2_1: R132.2, R142.1, U176.1
MIC2_2: R131.1, R141.1, R145.1, R171.1, U176.2
MIC2_3: R134.1, R144.2, U176.3
MIC2_VDD_3V3: C72.2, FB6.2, U176.4
MIC3N: C124.1, R170.2
MIC3P: C123.1, R177.2
MIC_L/R: R131.2, U7.22 (GPIO20)
MIC_MCLK: R127.2, R134.2
MIC_SD2: R132.1, R162.2
unnamed: R1.1, U9.1 (EN)
unnamed: L1.1, U9.3 (SW)
unnamed: FB7.1, U4.12
unnamed: FB10.1, U13.8 (VOP)
unnamed: R6.1, U1.1 (UD+)
unnamed: R7.1, U1.2 (UD-)
unnamed: R5.1, U8.2 (B1)
unnamed: R9.1, U8.5 (B2)
unnamed: J1.B5, R3.2
unnamed: R8.2, U1.9 (RXD)
unnamed: R10.2, U1.8 (TXD)
unnamed: R16.2, U2.6 (PRO)
unnamed: C26.1, R2.2, R11.1, U9.5 (FB)
unnamed: L6.1, U10.3 (SW)
unnamed: C151.2, IC7.3 (CE), R181.1
unnamed: R13.1, R210.2, U10.1 (EN)
unnamed: C143.2, U4.10
unnamed: R185.2, U4.8
unnamed: D1.3, R31.1, R121.1
unnamed: D1.4, R32.1, R120.1
unnamed: D14.+, R26.1
unnamed: J21.1, J21.2, P56.P$1, R25.2
unnamed: C174.2, J9.1, J9.1-1 (1), R49.1
unnamed: C177.2, J11.1, J11.1-1 (1), R48.1
unnamed: FB8.1, U4.14
unnamed: Q5.4 (4_G), R78.1, SW1.2 (2_COM2), SW1.5 (5_COM1)
unnamed: J1.A5, R4.1
unnamed: R79.1, U4.16
unnamed: C28.1, R24.1, R210.1, U10.4 (VIN)
unnamed: R90.1, U7.13 (GPIO12)
unnamed: R88.1, U7.12 (GPIO11)
unnamed: R190.2, U7.40 (DSI_DATAN0)
unnamed: R92.2, U7.39 (DSI_DATAP0)
unnamed: C30.1, R35.1, U7.1 (GPIO1), Y4.2
unnamed: C29.1, R35.2, U7.104 (GPIO0), Y4.1
unnamed: R95.2, U7.36 (DSI_DATAN1)
unnamed: R99.2, U7.35 (DSI_DATAP1)
unnamed: R100.2, U7.37 (DSI_CLKN)
unnamed: C147.2, R179.2
unnamed: R102.2, U7.38 (DSI_CLKP)
unnamed: R103.2, U7.78 (FB_DCDC)
unnamed: R104.2, U7.34 (DSI_REXT)
unnamed: C21.2, IC4.3 (CE), R53.1
unnamed: C135.2, R178.2
unnamed: FB2.1, U3.8 (VOP)
unnamed: FB11.1, U13.5 (VON)
unnamed: FB3.1, U3.5 (VON)
unnamed: R117.1, U3.1 (CTRL)
unnamed: R118.2, U5.3 (MISO/P1.4)
unnamed: R119.2, U5.4 (SCLK/P1.5)
unnamed: R139.1, R143.2, U13.1 (CTRL)
unnamed: IC5.3 (CDATA), R124.2
unnamed: IC5.4 (CCLK), R125.2
unnamed: FB9.1, U4.3
unnamed: C157.2, IC8.3 (CE), R116.1
unnamed: R164.2, U5.12 (P3.1/ADC9)
unnamed: R186.2, U5.11 (P3.0/ADC8)
unnamed: FB12.1, U4.5
unnamed: C124.2, IC5.32 (MIC3N)
unnamed: C89.1, IC5.15 (MIC1N)
unnamed: C101.1, IC5.16 (MIC1P)
unnamed: C162.2, R189.2, U5.7 (NRST/PWM6/P5.4)
unnamed: R332.1, U7.7 (GPIO7)
unnamed: R216.1, U7.6 (GPIO6)
unnamed: R191.2, U7.80 (GPIO39)
unnamed: R192.2, U7.84 (GPIO43)
unnamed: R193.2, U7.86 (GPIO44)
unnamed: R158.1, U7.48 (CSI_REXT)
unnamed: R157.1, U7.44 (CSI_CLKP)
unnamed: R156.1, U7.45 (CSI_CLKN)
unnamed: R155.1, U7.47 (CSI_DATAP1)
unnamed: R154.1, U7.46 (CSI_DATAN1)
unnamed: R152.1, U7.42 (CSI_DATAN0)
unnamed: J16.B5, R96.2
unnamed: J16.A5, R101.1
unnamed: C176.2, J11.5, J11.5-5 (5), R151.1
unnamed: C175.2, J11.6, J11.6-6 (6), R194.1
unnamed: C123.2, IC5.31 (MIC3P)
unnamed: C122.2, IC5.30 (REFQ34)
unnamed: C121.2, IC5.29 (REFP34)
unnamed: C76.2, IC2.3 (CE), R61.1
unnamed: C81.2, IC3.3 (CE), R66.1
unnamed: C86.2, R67.1, Y3.1 (1_EN)
unnamed: C120.2, IC5.28 (MIC4P)
unnamed: C119.2, IC5.27 (MIC4N)
unnamed: C118.2, IC5.26 (MICBIAS34)
unnamed: C117.2, IC5.25 (REFQM)
unnamed: C129.1, IC5.24 (MICBIAS12)
unnamed: C125.1, IC5.20 (MIC2N)
unnamed: C126.1, IC5.19 (MIC2P)
unnamed: C127.1, IC5.18 (REFQ12)
unnamed: C128.1, IC5.17 (REFP12)
unnamed: R147.2, U4.1
unnamed: C97.2, D017.1, D018.2
unnamed: IC5.1 (AD0), R73.2
unnamed: IC5.2 (AD1), R72.2
unnamed: C139.1, IC6.14 (DACVREF)
unnamed: C137.2, IC6.16 (VMID)
unnamed: C138.1, IC6.15 (ADCVREF)
unnamed: C140.1, IC6.13 (OUTN)
unnamed: C141.1, IC6.12 (OUTP)
unnamed: C142.1, FB13.1, IC6.11 (AVDD)
unnamed: D003.+, D012.2, L5.2, U6.1 (1-SW)
unnamed: C96.1, C97.1, D013.2, L2.2, U16.1 (1_SW)
unnamed: R165.2, U16.4 (4_EN)
unnamed: C96.2, D005.1, D015.2
unnamed: C93.2, R166.1, R167.2, U16.3 (3_FB)
unnamed: C98.1, D015.1, R172.2
unnamed: C140.2, R146.1, R170.1
unnamed: C109.1, D017.2, R174.2
unnamed: C141.2, R148.1, R177.1
P4_IO2: J7.9, U7.2 (GPIO2)
P4_IO3: J7.11, U7.3 (GPIO3)
P4_IO4: J7.13, U7.4 (GPIO4)
P4_IO5: J7.15, U7.5 (GPIO5)
P4_IO25: J7.17, U7.53 (GPIO25)
P4_IO35: R55.2, U7.66 (GPIO35)
P4_IO36: R60.2, U7.68 (GPIO36)
P4_IO49: J7.19, U7.92 (GPIO49)
P4_IO50: J7.20, U7.93 (GPIO50)
P4_IO51: J7.18, U7.94 (GPIO51)
P4_IO52: J7.16, U7.95 (GPIO52)
P4_IO53: J7.14, U7.97 (GPIO53)
P4_IO54: J7.12, U7.98 (GPIO54)
P4_RST_EN: C35.2, K4.2, R54.2, U7.103 (CHIP_PU), U8.6 (C1)
P4_RXD2: R48.2, U7.57 (GPIO28)
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

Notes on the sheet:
BOOT
RESET
HIG: SPI Boot
LOW: Download Boot
HIG: ESP32-P4 Enable
LOW: ESP32-P4 Off
Power_LED
USB interface
USB TO UART
Battery and control
ESP32-C6
7.0 inch IPS interface
SD card
Wireless module
UART & I2C & GPIO extensions
PDM MIC
UART_5V_IN
I2C_OUT
UART0_OUT
ESP32-P4
ESP32-P4_POWER
CSI_Interface
I led=200mV/0.75=160mA
DSI_LED Driver
Audio_OUT
DC-DC:5V to 3V3
DC-DC:5V to 1V2
Power SW
LCD_POWER
Charge indicator control
Audio_ADC/DAC
LDO:5V to 3V3(AUDIO POWER)
ESP32 P4-Advance HMI Display 10.1 V1.0

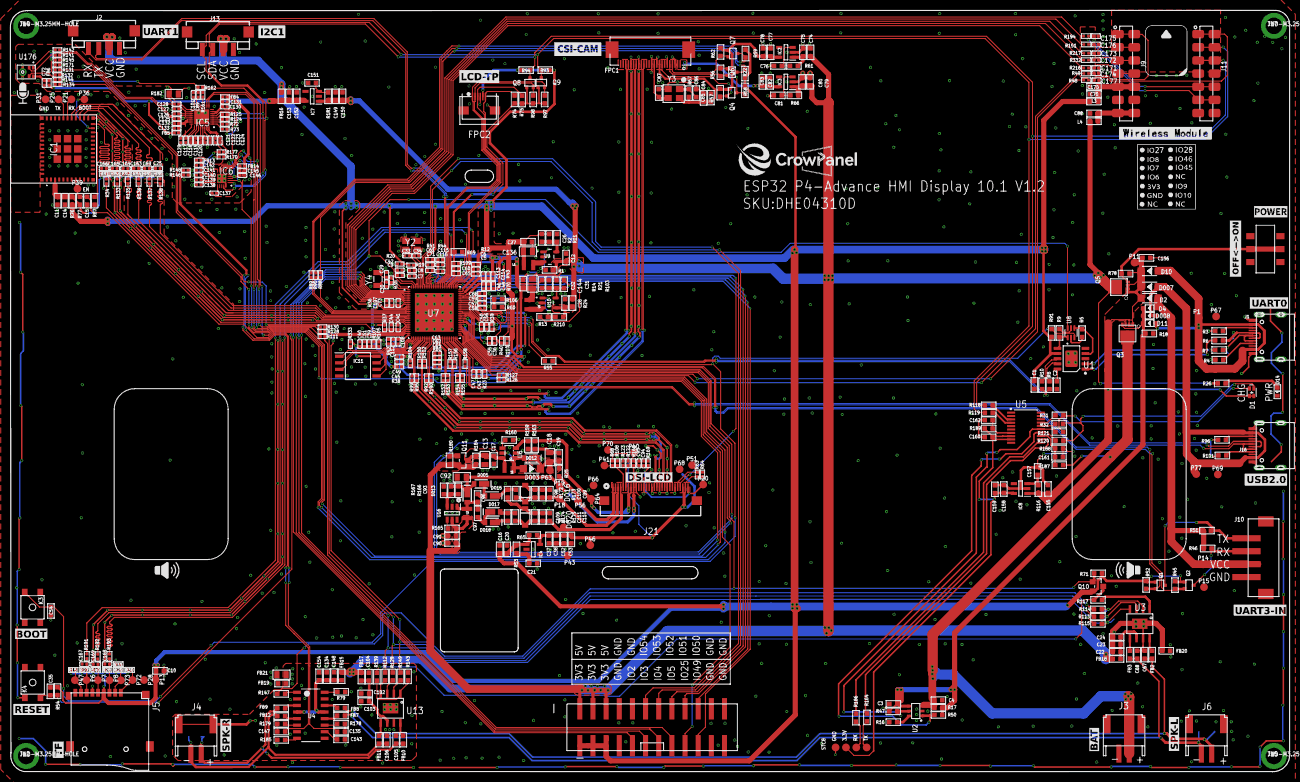
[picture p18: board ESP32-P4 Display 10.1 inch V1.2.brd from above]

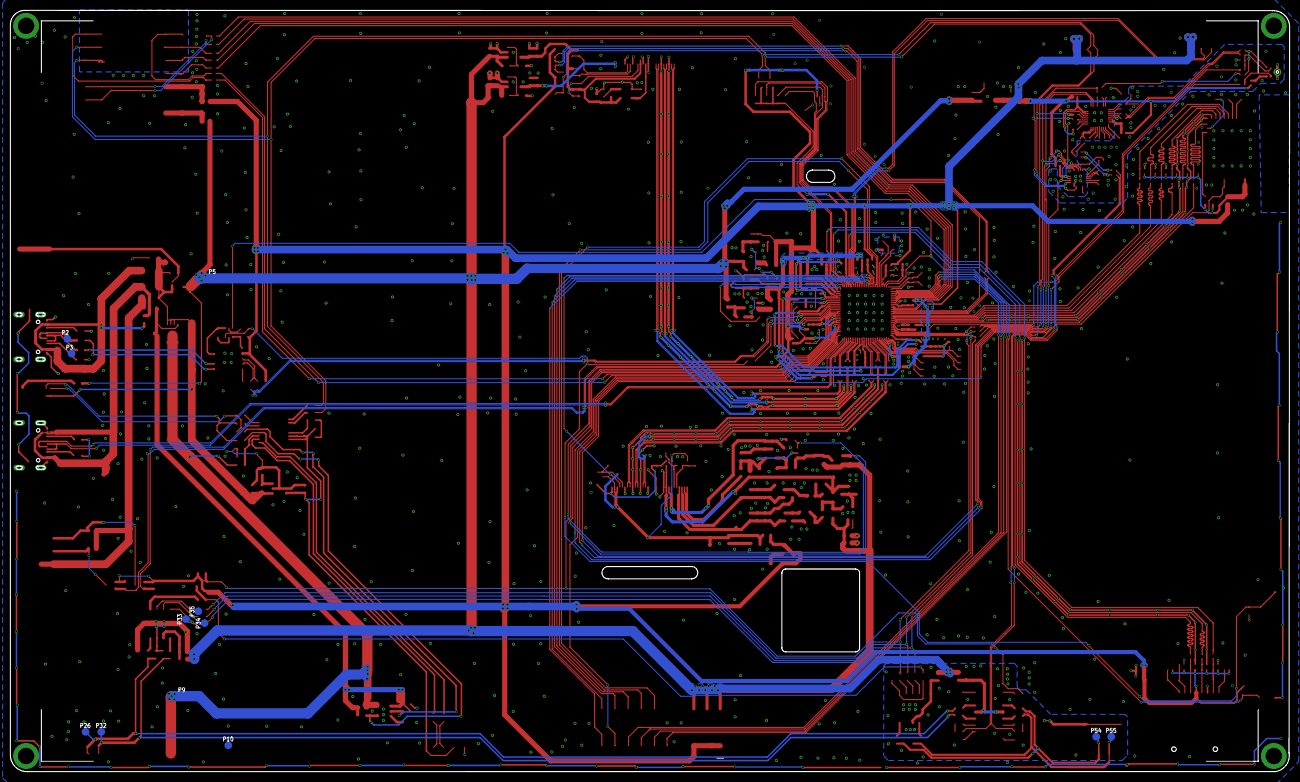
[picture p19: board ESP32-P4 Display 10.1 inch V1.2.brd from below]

Board: 2 copper layers, 247.0 x 147.0 mm, 522 parts (12 on the bottom side), 315 nets.

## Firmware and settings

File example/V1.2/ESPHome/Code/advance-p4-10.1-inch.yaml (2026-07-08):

# Board: Generic ESP32-P4 Board (Generic)
# Definition: definitions/boards/generic-esp32p4/manifest.yaml

esphome:
  name: advance-p4-10.1-inch
  friendly_name: Advance-P4-10.1-inch
  on_boot:
    priority: 800
    then:
      - logger.log: "Backlight ON"
      - output.turn_on: backlight_pwm
      - delay: 200ms
      - output.turn_off: power_light
      - delay: 500ms
  
      - light.turn_on:
          id: back_light
          brightness: 1
          
esp32:
  variant: esp32p4
  engineering_sample: true  
  cpu_frequency: 360MHZ
  flash_size: 16MB
  framework:
    type: esp-idf
    advanced:
      execute_from_psram: true
      enable_idf_experimental_features: true

psram:
  speed: 200MHz

esp_ldo:
  - channel: 3
    voltage: 2.5V
  - channel: 4
    voltage: 2.5V

# Enable logging
logger:
  level: debug
  logs:
    lvgl: info
  hardware_uart: UART0

# This board has no native Wi-Fi. ESPHome's ``api:`` and
# ``ota:`` components both require a ``network``
# component — configure ``openthread:`` / ``ethernet:`` /
# ``esp32_hosted:`` to suit your setup, then add ``api:``
# and ``ota:`` blocks once the network is ready.
# Enable Home Assistant API
api:
  encryption:
    key: LifObNGWp+y+qo+1zOE+UIUVc8RUqKdXjERGPRtIbfU=
    
ota:
  - platform: esphome
    password: "bf1c7324cdcd0f41044c7722cbf5a048"

esp32_hosted:
  variant: esp32c6
  active_high: true
  reset_pin: GPIO32
  cmd_pin: GPIO19
  clk_pin: GPIO18
  d0_pin: GPIO17
  d1_pin: GPIO16
  d2_pin: GPIO15
  d3_pin: GPIO14

wifi:
  ssid: !secret wifi_ssid
  password: !secret wifi_password

  # Enable fallback hotspot (captive portal) in case wifi connection fails
  ap:
    ssid: "Advance-P4-10.1-Inch"
    password: "eW0iGlqyJxnC"

captive_portal:

i2c:
  - id: bus_a
    sda: GPIO45
    scl: GPIO46
    frequency: 400kHz

sensor:
  - platform: aht10
    variant: AHT20
    temperature:
      name: "Room Temperature"
      id: room_temp
      unit_of_measurement: "°C"
      accuracy_decimals: 1
    humidity:
      name: "Room Humidity"
      id: room_hum
      unit_of_measurement: "%"
      accuracy_decimals: 1
    update_interval: 1s

touchscreen:
  - platform: gt911
    id: my_touchscreen
    i2c_id: bus_a
    reset_pin: 40
    interrupt_pin: 42
    update_interval: 50ms
    transform:
      swap_xy: false
      mirror_x: false
      mirror_y: false
    # Enabled Touch Logger here
    on_touch:
      - logger.log:
          format: "Touch at (%d, %d)"
          args: [touch.x, touch.y]
      - lambda: |-
          ESP_LOGI("cal", "x=%d, y=%d, x_raw=%d, y_raw=%d",
          touch.x,
          touch.y,
          touch.x_raw,
          touch.y_raw
          );

switch:
  - platform: gpio
    pin: GPIO48
    name: "LED"
    id: led_output
    on_turn_on:
      # Switch bulb diagram
      - lvgl.image.update:
          id: lvgl_light
          src: light_on
      # Switch the status label text to ON
      - lvgl.label.update:
          id: label_light_state
          text: "ON"
    on_turn_off:
      # Switch bulb diagram
      - lvgl.image.update:
          id: lvgl_light
          src: light_off
      # Switch the status label text to OFF
      - lvgl.label.update:
          id: label_light_state
          text: "OFF"

output:
  - platform: ledc
    pin: GPIO31
    id: backlight_pwm
  - platform: gpio
    id: power_light
    pin: GPIO29
    inverted: true
    
light:
  - platform: monochromatic
    name: "Backlight"
    output: backlight_pwm
    id: back_light
    restore_mode: ALWAYS_ON
    internal: true

display:
  - platform: mipi_dsi
    id: my_display
    model: WAVESHARE-ESP32-P4-WIFI6-TOUCH-LCD-7B
    reset_pin:
      number: 41
    update_interval: never
    auto_clear_enabled: false
    dimensions:
      width: 1024
      height: 600
    color_order: RGB
    color_depth: 16

image:
  - file: "small_temp.png"
    id: small_temp
    resize: 200x200
    type: RGB565
    byte_order: little_endian
  - file: "small_hum.png"
    id: small_hum
    resize: 200x200
    type: RGB565
    byte_order: little_endian
  - file: "small_logo.png"
    id: small_logo
    resize: 200x100
    type: RGB565
    byte_order: little_endian
  - file: "light.png"
    id: light_on
    resize: 200x200
    type: RGB565
    transparency: alpha_channel
    byte_order: little_endian
  - file: "no_light.png"
    id: light_off
    resize: 200x200
    type: RGB565
    transparency: alpha_channel
    byte_order: little_endian
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

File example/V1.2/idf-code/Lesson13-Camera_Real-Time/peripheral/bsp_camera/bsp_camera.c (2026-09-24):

/*---------------------------------------------------------------
 * Header file declarations
 *--------------------------------------------------------------*/
#include "bsp_camera.h"
#include "esp_cache.h"

/* SCCB (camera control) I2C bus handle. */
static i2c_master_bus_handle_t sccb_bus_handle = NULL;

/* LVGL canvas object that renders the camera frame. */
static lv_obj_t *camera_obj;

/* Camera video state: buffers, geometry, V4L2 buffer, callbacks. */
static camera_video_t camera_video;

/* Match the smooth Brookesia camera example: keep four capture buffers so
 * CSI can continue filling while LVGL synchronously displays one frame. */
#define CAMERA_BUFFER_COUNT 4
uint8_t *cam_buffer[CAMERA_BUFFER_COUNT];
size_t cam_buffer_size[CAMERA_BUFFER_COUNT];
int camera_video_id = 0;

static const uint8_t red_gain_lut[32] __attribute__((unused)) = {
    0,1,3,4,5,7,8,9,11,12,14,15,16,18,19,20,
    22,23,24,26,27,28,30,31,31,31,31,31,31,31,31,31
};
static const uint8_t green_gain_lut[64] __attribute__((unused)) = {
    0,1,2,3,4,5,6,7,8,8,9,10,11,12,13,14,
    15,16,17,18,19,20,21,22,23,24,25,26,27,28,29,30,
    30,31,32,33,34,35,36,37,38,39,39,40,41,42,43,44,
    45,46,47,48,49,50,51,52,53,54,55,55,56,57,58,59
};
static const uint8_t blue_gain_lut[32] __attribute__((unused)) = {
    0,1,1,2,3,3,4,5,5,6,7,7,8,9,9,10,
    11,12,12,13,14,14,15,16,16,17,18,18,19,20,20,21
};

/*---------------------------------------------------------------
 * Camera / SCCB initialisation
 *--------------------------------------------------------------*/

/**
 * @brief Initialise the camera SCCB bus and CSI video device.
 *
 * Creates the SCCB I2C master bus (SDA=12, SCL=13) and calls
 * esp_video_init to bring up the MIPI CSI receiver and detected
 * sensor.
 *
 * @return ESP_OK on success.
 */
esp_err_t camera_video_init(void)
{
    esp_err_t err = ESP_OK;

    i2c_master_bus_config_t sccb_conf = {
        .i2c_port = SCCB_MASTER_PORT,
        .sda_io_num = SCCB_GPIO_SDA,
        .scl_io_num = SCCB_GPIO_SCL,
        .clk_source = I2C_CLK_SRC_DEFAULT,
        .flags.enable_internal_pullup = true,
    };
    CAMERA_INFO("Initializing SCCB Bus.......");
    err = i2c_new_master_bus(&sccb_conf, &sccb_bus_handle);
    if (err != ESP_OK) {
        CAMERA_ERROR("failed to initialize SCCB bus: %s", esp_err_to_name(err));
        return err;
    }

    /* CSI init: reuse the SCCB bus handle for sensor register access. */
    esp_video_init_csi_config_t csi_config = {
        .sccb_config = {
            .init_sccb = true,
            .i2c_config = {
                .port = SCCB_MASTER_PORT,
                .scl_pin = SCCB_GPIO_SCL,
                .sda_pin = SCCB_GPIO_SDA,
            },
            .freq = 100000,
        },
        .reset_pin = -1,
        .pwdn_pin = -1,
    };
    csi_config.sccb_config.init_sccb = false;
    csi_config.sccb_config.i2c_handle = sccb_bus_handle;

    esp_video_init_config_t cam_config_ptr = {
        .csi = &csi_config,
    };
    err = esp_video_init(&cam_config_ptr);
    if (err != ESP_OK) {
        return err;
    }
    return err;
}

/*---------------------------------------------------------------
 * V4L2 video device open and format negotiation
 *--------------------------------------------------------------*/

/**
 * @brief Open the CSI video device and negotiate RGB565 format.
 *
 * Queries capabilities and current format, then forces RGB565 if
 * the sensor does not report it. Optionally applies vertical/
 * horizontal flip via V4L2 controls.
 *
 * @return File descriptor on success, -1 on failure.
 */
int video_open(void)
{
    struct v4l2_format camera_format;
    struct v4l2_capability capability;

#if CONFIG_ENABLE_CAM_SENSOR_PIC_VFLIP || CONFIG_ENABLE_CAM_SENSOR_PIC_HFLIP
    struct v4l2_ext_controls controls;
    struct v4l2_ext_control control[1];
#endif

    int fd = open(ESP_VIDEO_MIPI_CSI_DEVICE_NAME, O_RDONLY | O_NONBLOCK, 0);
    if (fd < 0) {
        CAMERA_ERROR("Open video failed");
        return -1;
    }

    if (ioctl(fd, VIDIOC_QUERYCAP, &capability)) {
        CAMERA_ERROR("failed to get capability");
        goto exit_0;
    }
    CAMERA_INFO("version: %d.%d.%d", (uint16_t)(capability.version >> 16),
               (uint8_t)(capability.version >> 8), (uint8_t)capability.version);
    CAMERA_INFO("driver:  %s", capability.driver);
    CAMERA_INFO("card:    %s", capability.card);
    CAMERA_INFO("bus:     %s", capability.bus_info);

    /* Query the current capture format and remember the geometry. */
    memset(&camera_format, 0, sizeof(struct v4l2_format));
    camera_format.type = V4L2_BUF_TYPE_VIDEO_CAPTURE;
    if (ioctl(fd, VIDIOC_G_FMT, &camera_format) != 0) {
        CAMERA_ERROR("failed to get format");
        goto exit_0;
    }
    CAMERA_INFO("initial format: %" PRIu32 "x%" PRIu32 " fourcc=0x%08" PRIx32
                " stride=%" PRIu32 " size=%" PRIu32,
                camera_format.fmt.pix.width, camera_format.fmt.pix.height,
                camera_format.fmt.pix.pixelformat, camera_format.fmt.pix.bytesperline,
                camera_format.fmt.pix.sizeimage);
    camera_video.camera_buf_hes = camera_format.fmt.pix.width;
    camera_video.camera_buf_ves = camera_format.fmt.pix.height;

    /* Force RGB565 if the sensor is not already in that format. */
    if (camera_format.fmt.pix.pixelformat != V4L2_PIX_FMT_RGB565) {
        struct v4l2_format format = {
            .type = V4L2_BUF_TYPE_VIDEO_CAPTURE,
            .fmt.pix.width = camera_format.fmt.pix.width,
            .fmt.pix.height = camera_format.fmt.pix.height,
            .fmt.pix.pixelformat = V4L2_PIX_FMT_RGB565,
        };
        if (ioctl(fd, VIDIOC_S_FMT, &format) != 0) {
            CAMERA_ERROR("failed to set format");
            goto exit_0;
        }
        camera_format = format;
    }
    if (camera_format.fmt.pix.pixelformat != V4L2_PIX_FMT_RGB565) {
        CAMERA_ERROR("driver did not accept RGB565 format");
        goto exit_0;
    }
    camera_video.camera_buf_hes = camera_format.fmt.pix.width;
    camera_video.camera_buf_ves = camera_format.fmt.pix.height;
    CAMERA_INFO("capture format: %" PRIu32 "x%" PRIu32 " RGB565"
                " stride=%" PRIu32 " size=%" PRIu32,
                camera_video.camera_buf_hes, camera_video.camera_buf_ves,
                camera_format.fmt.pix.bytesperline, camera_format.fmt.pix.sizeimage);
    CAMERA_INFO("app_video_open successful");

    /* Optional vertical flip. */
#if CONFIG_ENABLE_CAM_SENSOR_PIC_VFLIP
    controls.ctrl_class = V4L2_CTRL_CLASS_USER;
    controls.count = 1;
    controls.controls = control;
    control[0].id = V4L2_CID_VFLIP;
    control[0].value = 1;
    if (ioctl(fd, VIDIOC_S_EXT_CTRLS, &controls) != 0) {
        CAMERA_ERROR("failed to mirror the frame horizontally and skip this step");
    }
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

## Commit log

2026-03-18 add arduino
2026-05-12 sync idf lesson13
    [partitions.csv]
2026-06-04 sync example/V1.1 1.2
    [partitions.csv]
2026-06-04 sync example/V1.2
    [partitions.csv]
2026-07-30 更新代码 2026-07-30 18:18

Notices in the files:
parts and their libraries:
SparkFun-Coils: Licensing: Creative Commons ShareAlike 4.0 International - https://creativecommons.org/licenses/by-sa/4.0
